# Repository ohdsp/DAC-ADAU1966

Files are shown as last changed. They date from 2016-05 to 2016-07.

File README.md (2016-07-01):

# [Open Hardware DSP Platform](http://www.ohdsp.org)
## ADAU1966 DAC with passive output filters
### Revision 2.0
###### DAC-ADAU1966 (KiCad 4.0.2-stable)
---
# README
### Disclaimer
Copyright Paul Janicki 2016

Licensed under the TAPR Open Hardware License (www.tapr.org/OHL)

This documentation is distributed WITHOUT ANY EXPRESS OR IMPLIED WARRANTY, INCLUDING OF MERCHANTABILITY, SATISFACTORY QUALITY AND FITNESS FOR A PARTICULAR PURPOSE.

### What is this repository? ###

**Quick summary**

This is a digital to analogue converter based on the ADAU1966 DAC chip from Analog Devices. This is designed as part the Open Hardware DSP Platform. This may or may not be suitable for use in other applications. 

This simple 16 channel DAC is designed to be used with 4xTDM4, 2xTDM8 or 1xTDM16 data inputs supported on devices such as the ADAU1452. This board can be used with the ADAU1966 in standalone mode (no host microcontroller needed) or with an external I2C interface to program/control the ADAU1966. The board uses only passive output filters on the ADAU1966 but can easily drive external PCBs through appropriate cabling.

This repository contains the KiCad design files, manufacturing Gerber/drill files, and PDF/drawing files for this board.

### What is the project folder structure?
Most folder names are self explanatory. Starting from the top level: \
*DAC-ADAU1966*
+ *Bill of Materials*  - This contains the bill of materials in CVS, LibreOffice Calc and XML formats
+ *Drawings*
    + *PCB* - This contains SVG and PDF outputs of PCB copper layers and assembly drawings
    + *Schematics* - This contains the PDF schematic drawing
+ *Gerbers* - This contains the PCB Gerbers and drill drawings for manufacture, there is also a zip file ready to send to most manufacturers
+ *KiCad* - This contains the original KiCad schematic and PCB design files

### How do I get set up? ###

**Summary of set up**

1. Set your self up a directory on a local disk, something simple will make life easier (eg C:\Electronics on Windows as used here), but anywhere will do just fine.
2. Download the Kicad-Libs from [https://github.com/ohdsp/KiCad-Libs](https://github.com/ohdsp/KiCad-Libs) and place in C:\Electronics\Kicad-Libs (or your chosen folder) 
3. Create a OHDSP subdirectory in C:\Electronics (so C:\Electronics\OHDSP)
3. Download this project to C:\Electronics\OHDSP\DAC-ADAU1966
4. Fire up Kicad
5. Open the main project file C:\Electronics\OHDSP\DAC-ADAU1966\Schematics\DAC-ADAU1966.pro
6. (Optional) Setup Pcbnew component library as below.
7. Do as you wish with the project, just keep it under the TAPR Open Hardware License.

Make sure your git setup doesn't exclude files used in the project (like .LIB files) or things may go wrong down the line.

**KiCad Library Configuration**

Note that you need to setup a Pcbnew library, but the eeschema libraries should work without any changes if you followed the instructions above.

To setup Pcbnew libraries:

In Pcbnew go to Preferences -> Footprint Libraries Manager. Under Global Libraries tab in the top list check if there is a nickname "MyKiCadLibs-Footprints" (usually at the end of the list). If there is but it points to the wrong place then change the Library Path to point to MyKiCadLibs-Footprints (eg C:\Electronics\KiCad-Libs\MyKiCadLibs-Footprints.pretty) folder for your setup. If this is missing you can use "Append with Wizard", choose "Files on my computer", click next, browse to library location (eg C:\Electronics\KiCad-Libs\MyKiCadLibs-Footprints.pretty) and select the folder MyKiCadLibs-Footprints.pretty, click next, check the Status column states OK and the Format is KiCad (if not re-download the library) and click next, then select "To global library configuration..." and click Finish.

To setup eeschema component libraries:
Either from KiCad project window go to Tools -> Run Library Editor OR under eeschema, go to Tools -> Library Editor. Then Preferences -> Component Libraries.

The top section "Component Library Files" should ideally contain only two libraries, the "power" library that ships with KiCad and "MyKiCadLibs-Lib" available from above. To setup MyKiCadLibs-Lib as a relative path under the "User defined search path" click add. Browse to the location of KiCad-Libs you download above (eg C:\Electronics\KiCad-Libs) and click "Select Folder". Say yes to add a relative path. Under component library files click add, browse to the KiCad-libs again (eg C:\Electronics\KiCad-Libs), select file "MyKiCadLibs-Lib.lib" and click open. MyKiCadLibs-lib should appear in the component library list with no path as it will be using the user defined search path set in the box below.

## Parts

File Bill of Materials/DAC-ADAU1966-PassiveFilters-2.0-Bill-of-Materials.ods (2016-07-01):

DAC-ADAU1966 Bill of Materials – Revision 2.0
25 May 2016
Reference | Quantity | Footprint | Value | Description | Power | Size | Tolerance | Voltage | Type | Current
C301 C306 C312 | 3 | CAP-TH-D8mmP3.5mm | 220u | 'Aluminium electrolytic low impedance capacitor - eg Panasonic FC or FR parts | ' | '3.5mm Pitch, 8mm Diameter | ' | '25V | ' | '
C302 C307 C308 C315 | 4 | SMD-0805 | 22u | 'Ceramic capacitor | ' | '0805 | '20% | '25V | 'X5R | '
C303 C310 C311 C316 C321 C324 C328 C404 C422 C426 C428 C430 C434 C436 C439 C441 C446 C450 C460 | 19 | SMD-0805 | 100n | 'Ceramic capacitor | ' | '0805 | '10% | '50V | 'X7R | '
C305 C313 C314 C318 C322 C326 C329 C447 C451 | 9 | SMD-0805 | 10n | 'Ceramic capacitor | ' | '0805 | '10% | '50V | 'X7R | '
C304 C309 C401 C419 C437 | 5 | SMD-0805 | 100p | 'Ceramic capacitor | ' | '0805 | '5% | '50V | 'C0G | '
C325 C402 C418 C421 C424 C438 | 6 | CAP-TH-D6.3mmP2.5mm | 220u | 'Aluminium electrolytic low impedance capacitor - eg Panasonic FC or FR parts | ' | '2.5mm Pitch, 6.3mm Diameter | ' | '10V | ' | '
C317 C320 C323 C327 C403 C416 C420 C423 C427 C440 | 10 | SMD-0805 | 22u | 'Ceramic capacitor | ' | '0805 | '20% | '10V | 'X5R | '
C405 C408 C412 C429 C432 C452 C454 C456 C458 | 9 | SMD-0603 | 1u | 'Ceramic capacitor | ' | '0603 | '10% | '10V | 'X7R | '
C406 C409 C414 C417 C431 C433 C453 C455 C457 C459 | 10 | SMD-0603 | 100n | 'Ceramic capacitor | ' | '0603 | '10% | '50V | 'X7R | '
C407 C410 C415 | 3 | SMD-0603 | 10n | 'Ceramic capacitor | ' | '0603 | '10% | '50V | 'X7R | '
C411 | 1 | SMD-0603 | 5n6 | 'Ceramic capacitor | ' | '0603 | '10% | '50V | 'X7R | '
C413 | 1 | SMD-0603 | 390p | 'Ceramic capacitor | ' | '0603 | '5% | '50V | 'C0G | '
C425 C461 | 2 | SMD-0805 | 10u | 'Ceramic capacitor | ' | '0805 | '20% | '10V | 'X5R | '
C435 | 1 | SMD-0805 | N/F | 'Ceramic capacitor | ' | '0805 | '10% | '50V | 'X7R | '
C442 C444 C445 C448 | 4 | SMD-0603 | 470n | 'Ceramic capacitor | ' | '0603 | '10% | '10V | 'X7R | '
C443 C449 | 2 | CAP-TH-D6.3mmP2.5mm | 47u | 'Aluminium electrolytic low impedance capacitor - eg Panasonic FC or FR parts | ' | '2.5mm Pitch, 6.3mm Diameter | ' | '10V | ' | '
C501 C502 C503 C504 C505 C506 C507 C508 C509 C510 C511 C512 C513 C514 C515 C516 | 16 | SMD-0805 | 2n7 | 'Ceramic capacitor | ' | '0805 | '5% | '50V | 'C0G | '
D301 D302 D303 D304 D306 D307 D308 D310 | 8 | DIODE-SOD-123 | SS14L | 'SS14L 1A 40V Schottky rectifier - Sub-SMA (SOD-123) | ' | ' | ' | ' | ' | '
D305 | 1 | DIODE-SOD-123 | B130LAW-7-F | '1A 30V Schottky Rectifier - SOD-123 - Low Vf (<0.3V@100mA) | ' | ' | ' | ' | ' | '
D309 | 1 | SMD-1206 | Green LED 1206 | 'Green LED - SMD - Vf 1.8V to 2.2V | ' | '1206 | ' | ' | ' | '
FID1 FID2 FID3 FID4 | 4 | FID-1MM-3MM | MNT_HOLE | 'Fiducial | ' | ' | ' | ' | ' | '
JP401 JP402 JP403 JP404 JP405 JP406 JP407 P410 | 8 | CONN_SIL_2_1MM | CONN_2x1 | '1x2 2.54mm pitch pin header | ' | ' | ' | ' | ' | '
L301 L302 L401 L402 L403 | 5 | SMD-0805 | 600R@100MHz | 'Ferrite bead, current rating 0.3A or higher, 600R@100MHz | ' | '0805 | ' | ' | ' | '=>0.3A
MNT301 MNT302 MNT303 MNT304 | 4 | MNT_HOLE_3.2mm | MNT_HOLE
P201 P202 P203 P204 | 4 | CONN_DIL_2X5_BOX_1MM | CONN_02X05 | '2x5 2.54mm pitch box header | ' | ' | ' | ' | ' | '
P205 | 1 | CONN_SIL_3_1MM | CONN_3x1 | '1x3 2.54mm pitch pin header | ' | ' | ' | ' | ' | '
P206 | 1 | CONN_DIL_2X6_BOX_1MM | CONN_02X06 | '2x6 2.54mm pitch box header | ' | ' | ' | ' | ' | '
P303 P304 | 2 | CONN-2WAY-2.54mm-3.81mm-SPACING | CONN_2x1 | '2 way screw terminal, 2.54mm to 3.81mm pitch | ' | ' | ' | ' | ' | '
P501 P502 P503 P504 | 4 | CONN_DIL_2X10_BOX_1MM | CONN_02X10 | '2x10 2.54mm pitch box header | ' | ' | ' | ' | ' | '
R101 R102 R419 | 3 | SMD-0805 | 1k | 'Thick or thin film resistor | '100mW | '0805 | '1% | ' | ' | '
R201 R202 R203 R204 R205 R206 R207 R214 R215 | 9 | SMD-0805 | N/F | 'Thick or thin film resistor | '100mW | '0805 | '1% | ' | ' | '
R208 R209 R210 R211 R212 R213 R216 R217 R218 R401 R405 R407 R409 R412 R414 R416 | 16 | SMD-0805 | 10k | 'Thick or thin film resistor | '100mW | '0805 | '1% | ' | ' | '
R219 R220 R221 R222 R223 R224 R225 R227 R228 R229 R230 R231 R310 | 13 | SMD-0805 | 0 | 'Thick or thin film resistor | '100mW | '0805 | '1% | ' | ' | '
R226 | 1 | SMD-0805 | 75 | 'Thick or thin film resistor | '100mW | '0805 | '1% | ' | ' | '
R301 R302 R402 R418 R422 | 5 | SMD-0805 | 47 | 'Thick or thin film resistor | '100mW | '0805 | '1% | ' | ' | '
R303 | 1 | SMD-0805 | 47k | 'Thick or thin film resistor | '100mW | '0805 | '1% | ' | ' | '
R309 | 1 | SMD-0805 | 2k2 | 'Thick or thin film resistor | '100mW | '0805 | '1% | ' | ' | '
R311 | 1 | SMD-0805 | 6k8 | 'Thick or thin film resistor | '100mW | '0805 | '1% | ' | ' | '
R312 | 1 | SMD-0805 | 470 | 'Thick or thin film resistor | '100mW | '0805 | '1% | ' | ' | '
R411 | 1 | SMD-0603 | 562 | 'Thick or thin film resistor | '100mW | '0805 | '1% | ' | ' | '
R420 | 1 | SMD-0805 | 100k | 'Thick or thin film resistor | '100mW | '0805 | '1% | ' | ' | '
R421 | 1 | SMD-0805 | 100 | 'Thick or thin film resistor | '100mW | '0805 | '1% | ' | ' | '
R501 R502 R503 R504 R505 R506 R507 R508 R509 R510 R511 R512 R513 R514 R515 R516 R549 R550 R551 R552 R553 R554 R555 R556 R557 R558 R559 R560 R561 R562 R563 R564 | 32 | SMD-1206 | 240 | 'MELF0204 1% =>250mW or 1206 1% =>250mW | '250mW | '1206 | '1% | ' | ' | '
R517 R518 R519 R520 R521 R522 R523 R524 R525 R526 R527 R528 R529 R530 R531 R532 R565 R566 R567 R568 R569 R570 R571 R572 R573 R574 R575 R576 R577 R578 R579 R580 | 32 | SMD-1206 | 100 | 'MELF0204 1% =>250mW or 1206 1% =>250mW | '250mW | '1206 | '1% | ' | ' | '
R533 R534 R535 R536 R537 R538 R539 R540 R541 R542 R543 R544 R545 R546 R547 R548 R581 R582 R583 R584 R585 R586 R587 R588 R589 R590 R591 R592 R593 R594 R595 R596 | 32 | SMD-1206 | 100k | 'MELF0204 1% =>250mW or 1206 1% =>250mW | '250mW | '1206 | '1% | ' | ' | '
TP101 | 1 | TP-1mm | Test point | '1mm test point | ' | ' | ' | ' | ' | '
TP401 TP402 | 2 | TP-2mm | Test point | 'Test point | ' | ' | ' | ' | ' | '
U301 | 1 | IC-SOT-223 | TLV1117LV33DCY | 'TLV1117LV 1-A, Positive Fixed-Voltage, Low-Dropout Regulator - Fixed 3V3 | ' | ' | ' | ' | ' | '
U302 | 1 | IC-SOT23-5 | TLV70025DDC | 'TLV700 200-mA, Low-IQ, Low-Dropout Regulator for Portable Devices - Fixed 2V5 | ' | ' | ' | ' | ' | '
U303 | 1 | IC-SOT223-6 | TPS7A4501 | 'TPS7A45xx Low-Noise Fast-Transient-Response 1.5-A Low-Dropout Voltage Regulators - Adjustable | ' | ' | ' | ' | ' | '
U401 | 1 | IC-SOT143 | ADM811ZART | 'Microprocessor Supervisory - 2V32 Typical Threshold | ' | ' | ' | ' | ' | '
U402 | 1 | IC-LQFP80-P065 | IC-DAC-ADAU1966 | '16-Channel High Performance Differential Output, 192 kHz, 24-Bit DAC | ' | ' | ' | ' | ' | '

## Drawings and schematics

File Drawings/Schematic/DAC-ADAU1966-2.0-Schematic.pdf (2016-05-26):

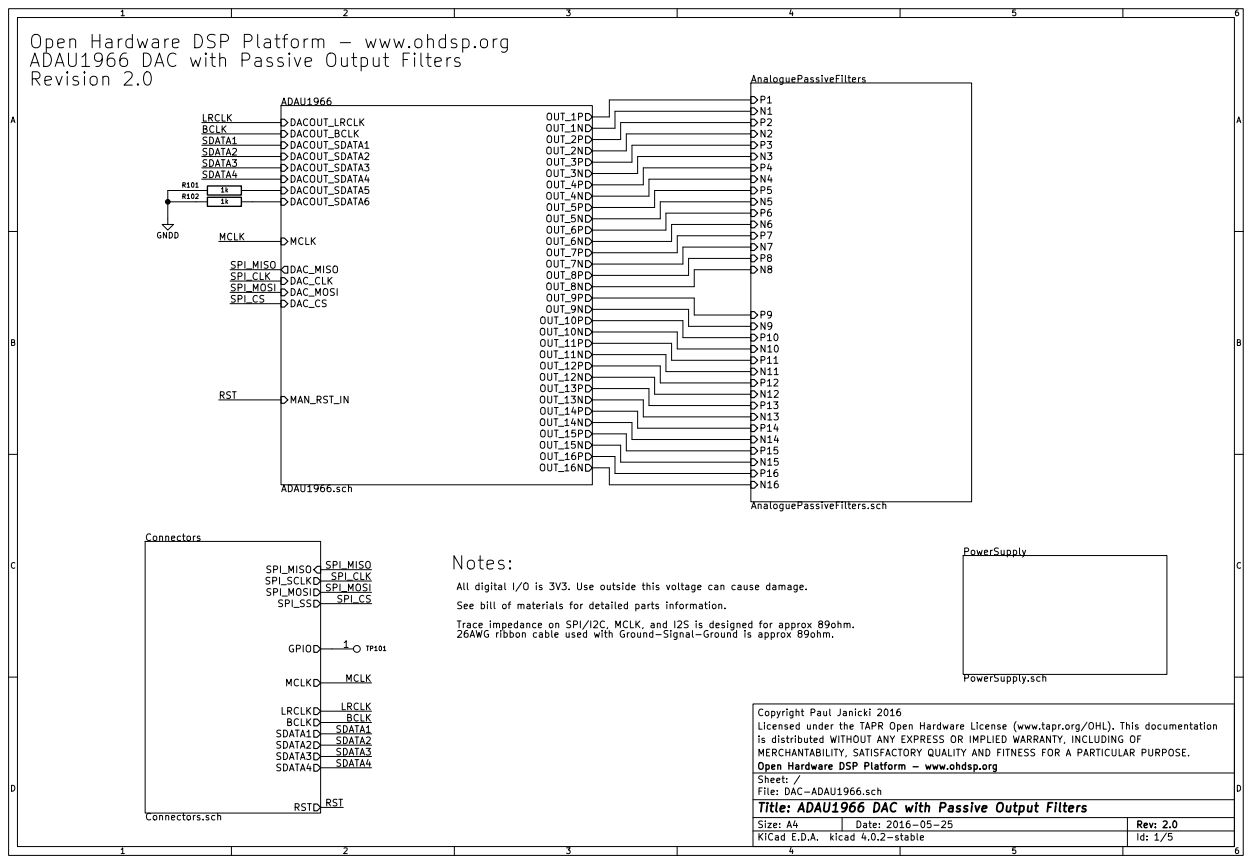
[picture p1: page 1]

AnaloguePassiveFilters.sch P1N1P2N2P3N3P4N4P5N5P6N6P7N7P8N8P9N9P10 N10 P11 N11 P12 N12 P13 N13 P14 N14 P15 N15 P16 N16 Open Hardware DSP Platform - www.ohdsp.org
ADAU1966 DAC with Passive Output Filters
Revision 2.0

SPI_CLK
SPI_MOSI

All digital I/O is 3V3. Use outside this voltage can cause damage.
See bill of materials for detailed parts information.
Trace impedance on SPI/I2C, MCLK, and I2S is designed for approx 89ohm.
26AWG ribbon cable used with Ground-Signal-Ground is approx 89ohm.

Copyright Paul Janicki 2016
Licensed under the TAPR Open Hardware License (www.tapr.org/OHL). This documentation
is distributed WITHOUT ANY EXPRESS OR IMPLIED WARRANTY, INCLUDING OF
MERCHANTABILITY, SATISFACTORY QUALITY AND FITNESS FOR A PARTICULAR PURPOSE.
File: DAC-ADAU1966.sch Sheet: / Open Hardware DSP Platform - www.ohdsp.org

Id: 1/5 Title: ADAU1966 DAC with Passive Output Filters

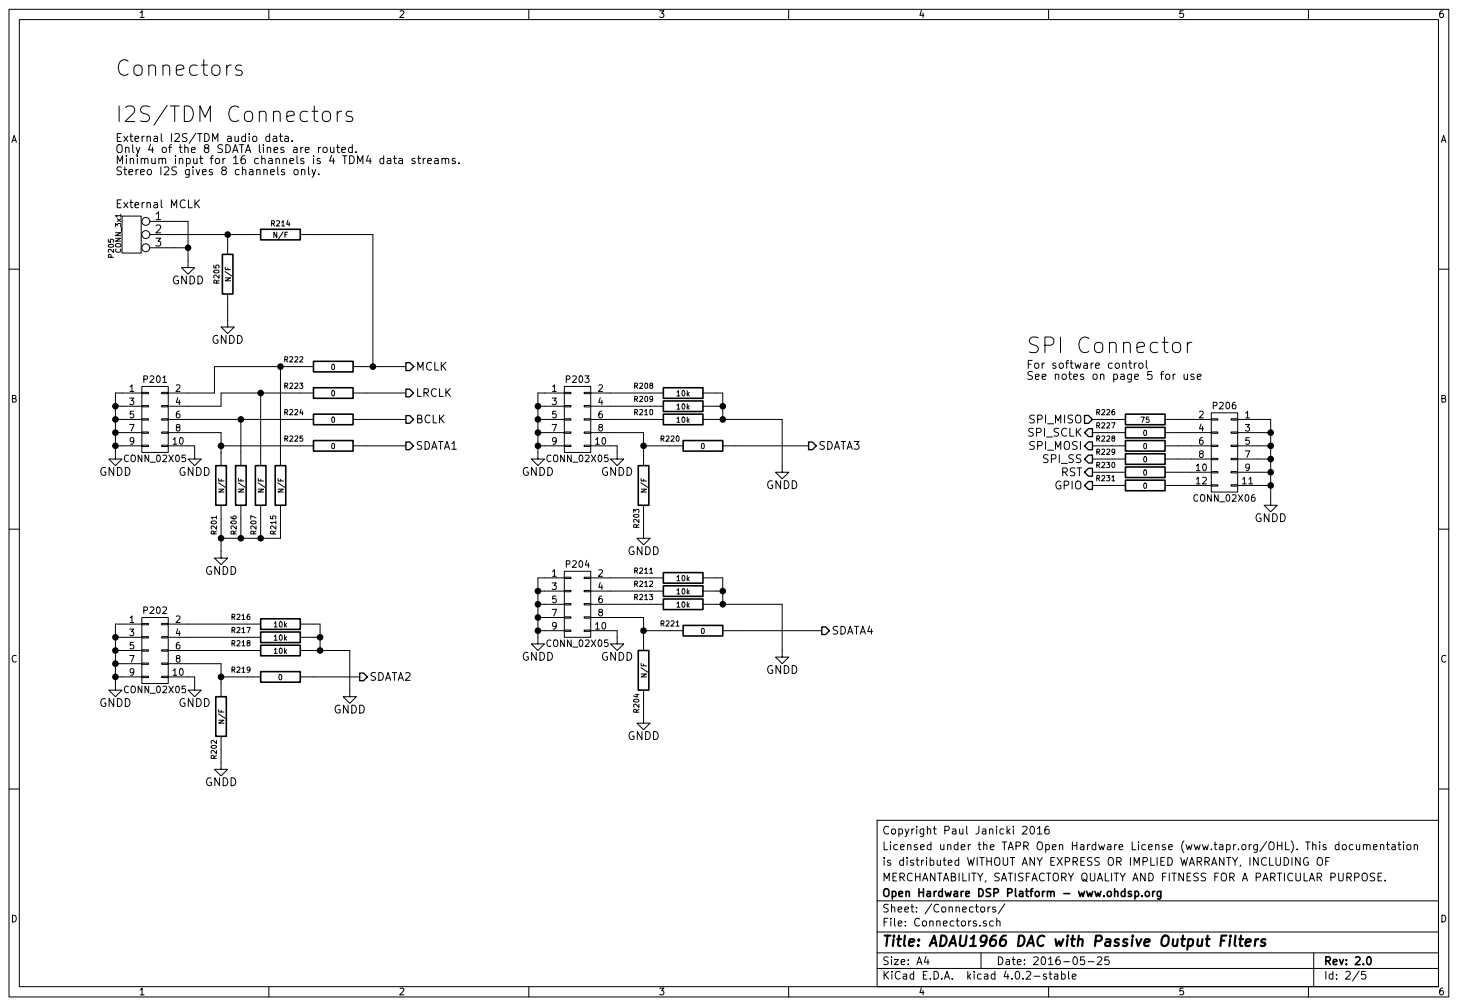
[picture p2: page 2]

External I2S/TDM audio data.
Only 4 of the 8 SDATA lines are routed.
Minimum input for 16 channels is 4 TDM4 data streams.
Stereo I2S gives 8 channels only.

0 For software control See notes on page 5 for use

10 | 9

Copyright Paul Janicki 2016
Licensed under the TAPR Open Hardware License (www.tapr.org/OHL). This documentation
is distributed WITHOUT ANY EXPRESS OR IMPLIED WARRANTY, INCLUDING OF
MERCHANTABILITY, SATISFACTORY QUALITY AND FITNESS FOR A PARTICULAR PURPOSE.
File: Connectors.sch Sheet: /Connectors/ Open Hardware DSP Platform - www.ohdsp.org

Id: 2/5 Title: ADAU1966 DAC with Passive Output Filters

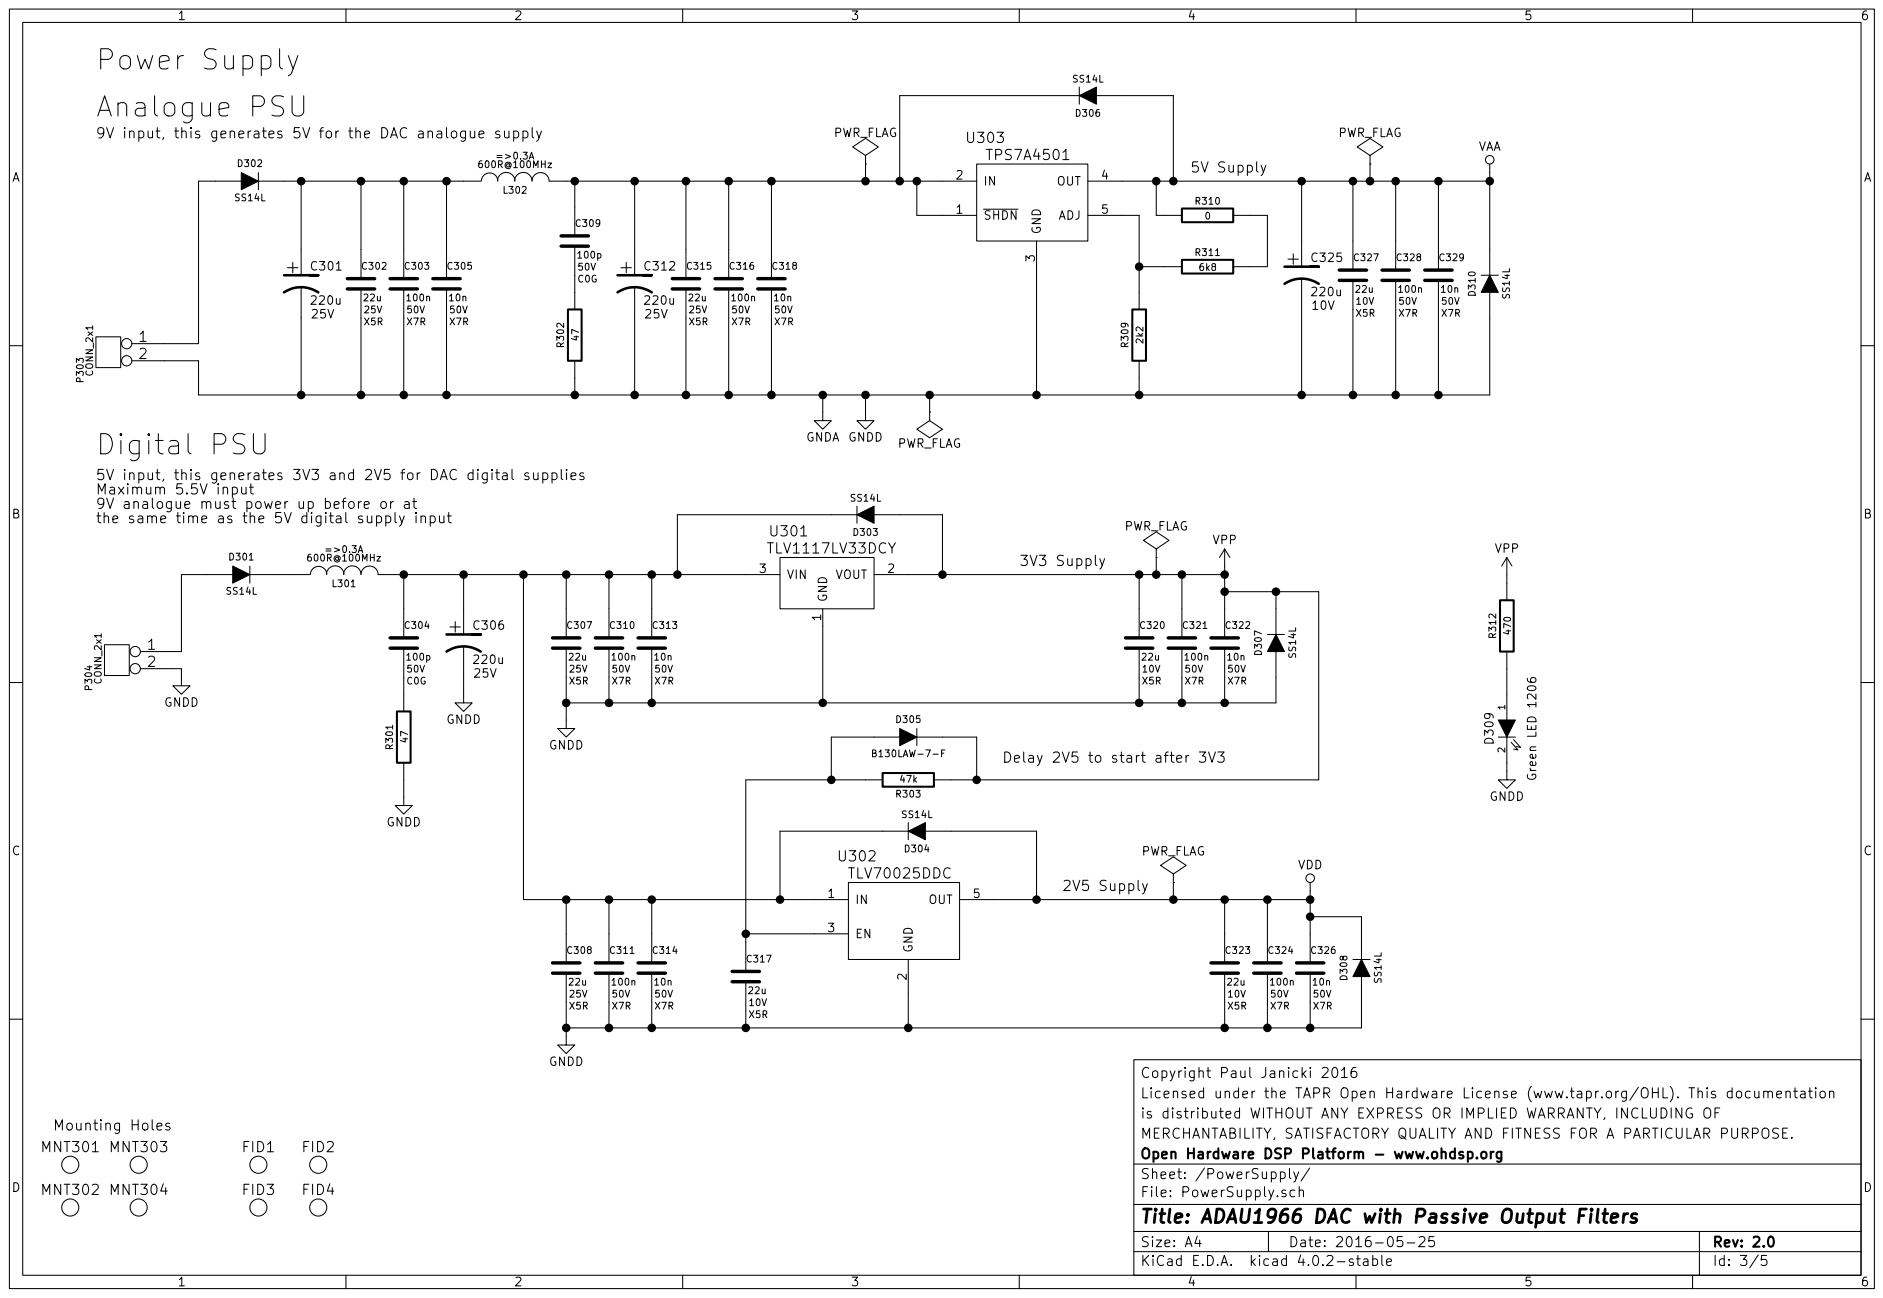
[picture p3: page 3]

9V input, this generates 5V for the DAC analogue supply

Copyright Paul Janicki 2016 GNDA GNDD

5V input, this generates 3V3 and 2V5 for DAC digital supplies
Maximum 5.5V input
9V analogue must power up before or at
the same time as the 5V digital supply input

Licensed under the TAPR Open Hardware License (www.tapr.org/OHL). This documentation
is distributed WITHOUT ANY EXPRESS OR IMPLIED WARRANTY, INCLUDING OF
MERCHANTABILITY, SATISFACTORY QUALITY AND FITNESS FOR A PARTICULAR PURPOSE.
Open Hardware DSP Platform - www.ohdsp.org
Sheet: /PowerSupply/
File: PowerSupply.sch
Id: 3/5 Title: ADAU1966 DAC with Passive Output Filters

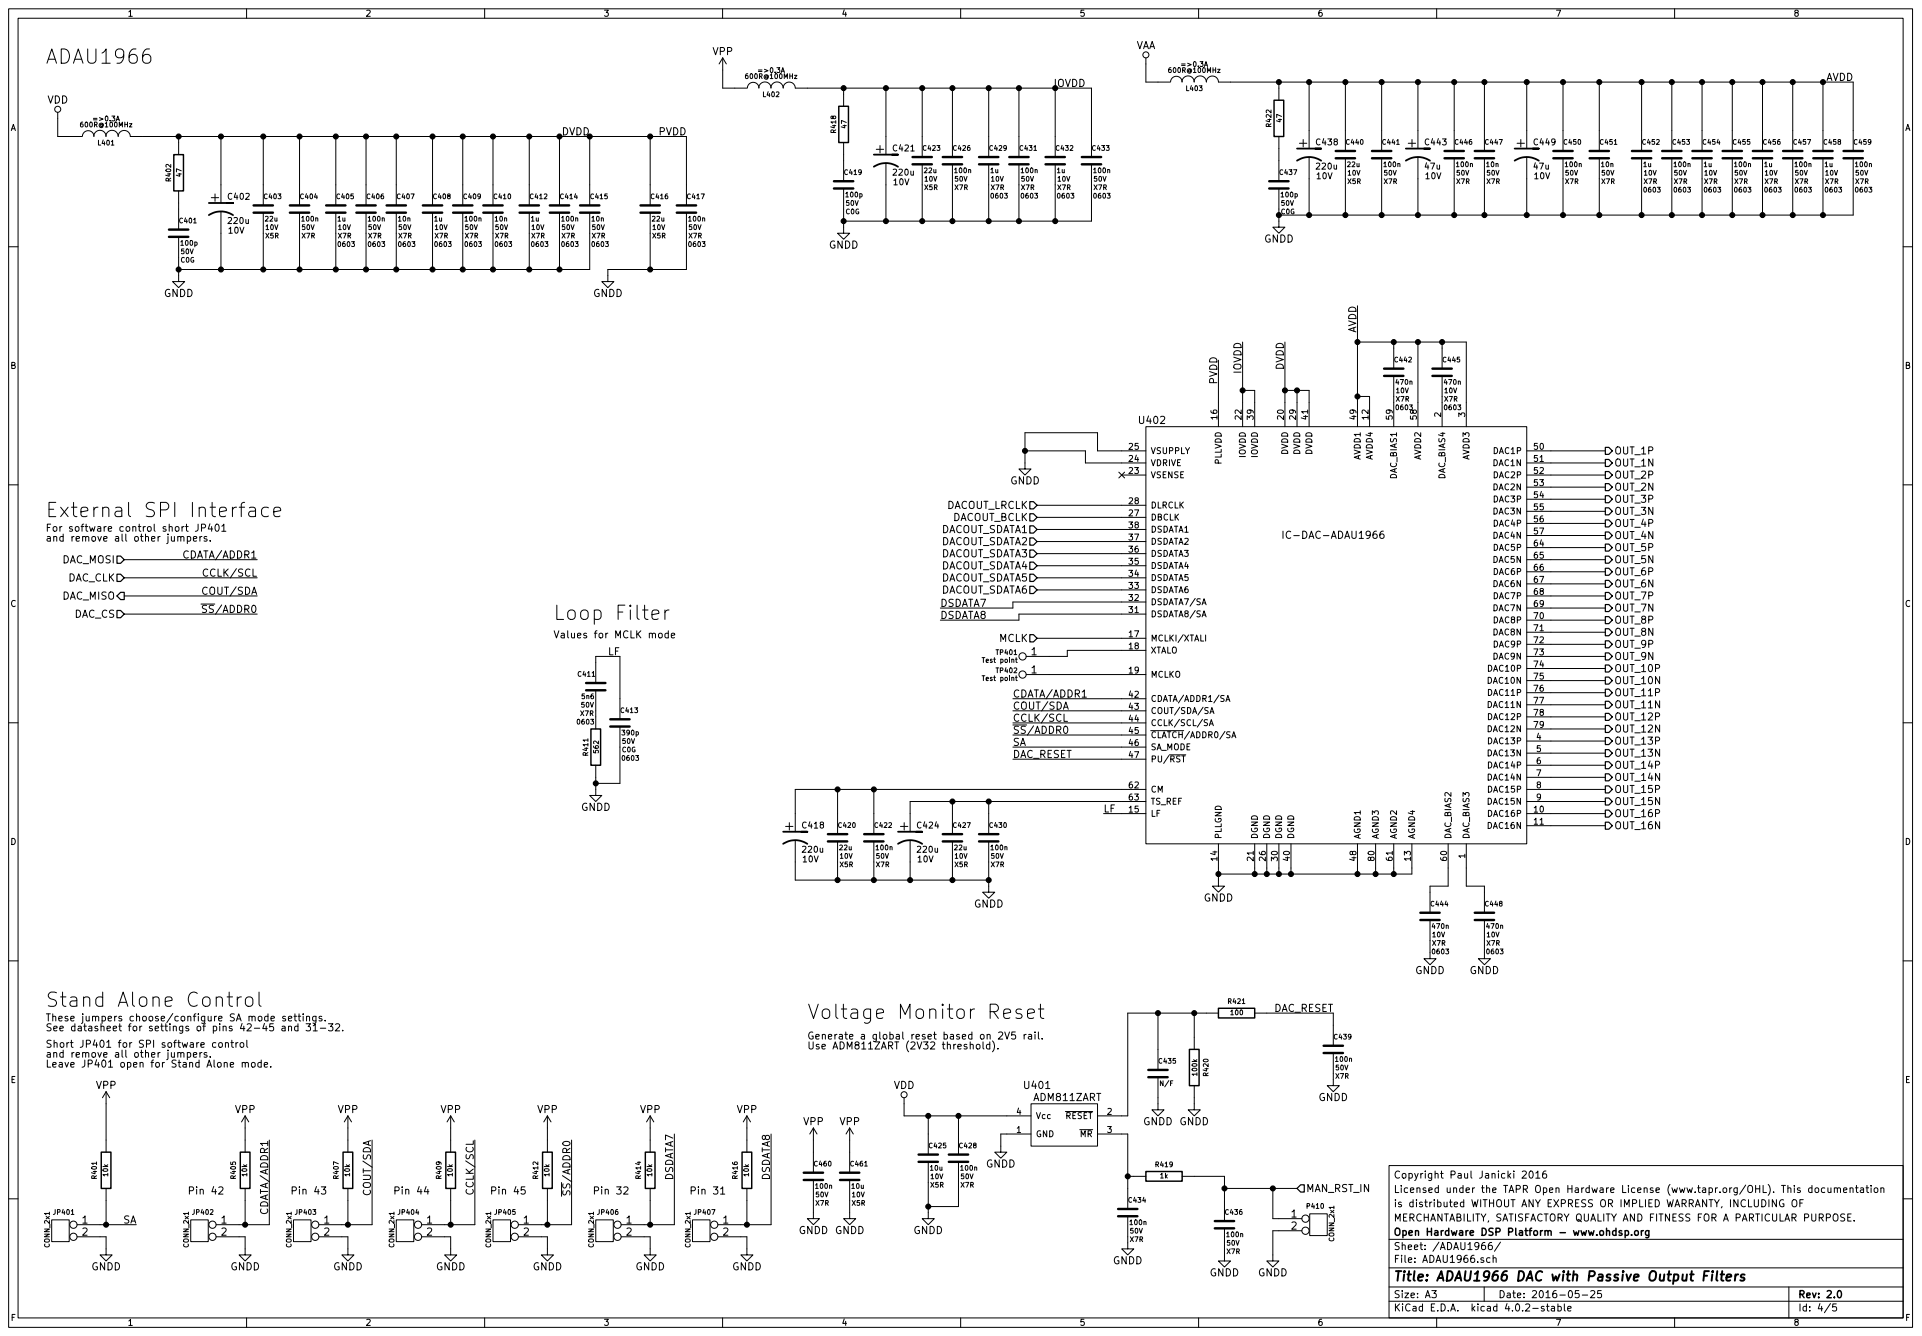
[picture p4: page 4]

3 DAC13P 4 DAC13N 5 DAC14P 6 DAC14N 7 DAC15P 8 DAC15N 9 DAC16P 10 DVDD 20 DGND 30 DGND 40 DAC1P 50 DAC_BIAS2 60 DAC8P 70 AGND3 80 DAC16N 11 DGND 21 DSDATA8/SA 31 DVDD 41 DAC1N 51 AGND2 61 DAC8N 71 AVDD4 12 IOVDD 22 DSDATA7/SA 32 CDATA/ADDR1/SA 42 DAC2P 52 CM 62 DAC9P 72 AGND4 13 VSENSE 23 DSDATA6 33 COUT/SDA/SA 43 DAC2N 53 TS_REF 63 DAC9N 73 PLLGND 14 VDRIVE 24 DSDATA5 34 CCLK/SCL/SA 44 DAC3P 54 DAC5P 64 DAC10P 74

These jumpers choose/configure SA mode settings.
See datasheet for settings of pins 42-45 and 31-32.
Short JP401 for SPI software control and remove all other jumpers.
Leave JP401 open for Stand Alone mode.

Generate a global reset based on 2V5 rail.
Use ADM811ZART (2V32 threshold).

Copyright Paul Janicki 2016
Licensed under the TAPR Open Hardware License (www.tapr.org/OHL). This documentation
is distributed WITHOUT ANY EXPRESS OR IMPLIED WARRANTY, INCLUDING OF
MERCHANTABILITY, SATISFACTORY QUALITY AND FITNESS FOR A PARTICULAR PURPOSE.
File: ADAU1966.sch Sheet: /ADAU1966/ Open Hardware DSP Platform - www.ohdsp.org

Id: 4/5 Title: ADAU1966 DAC with Passive Output Filters

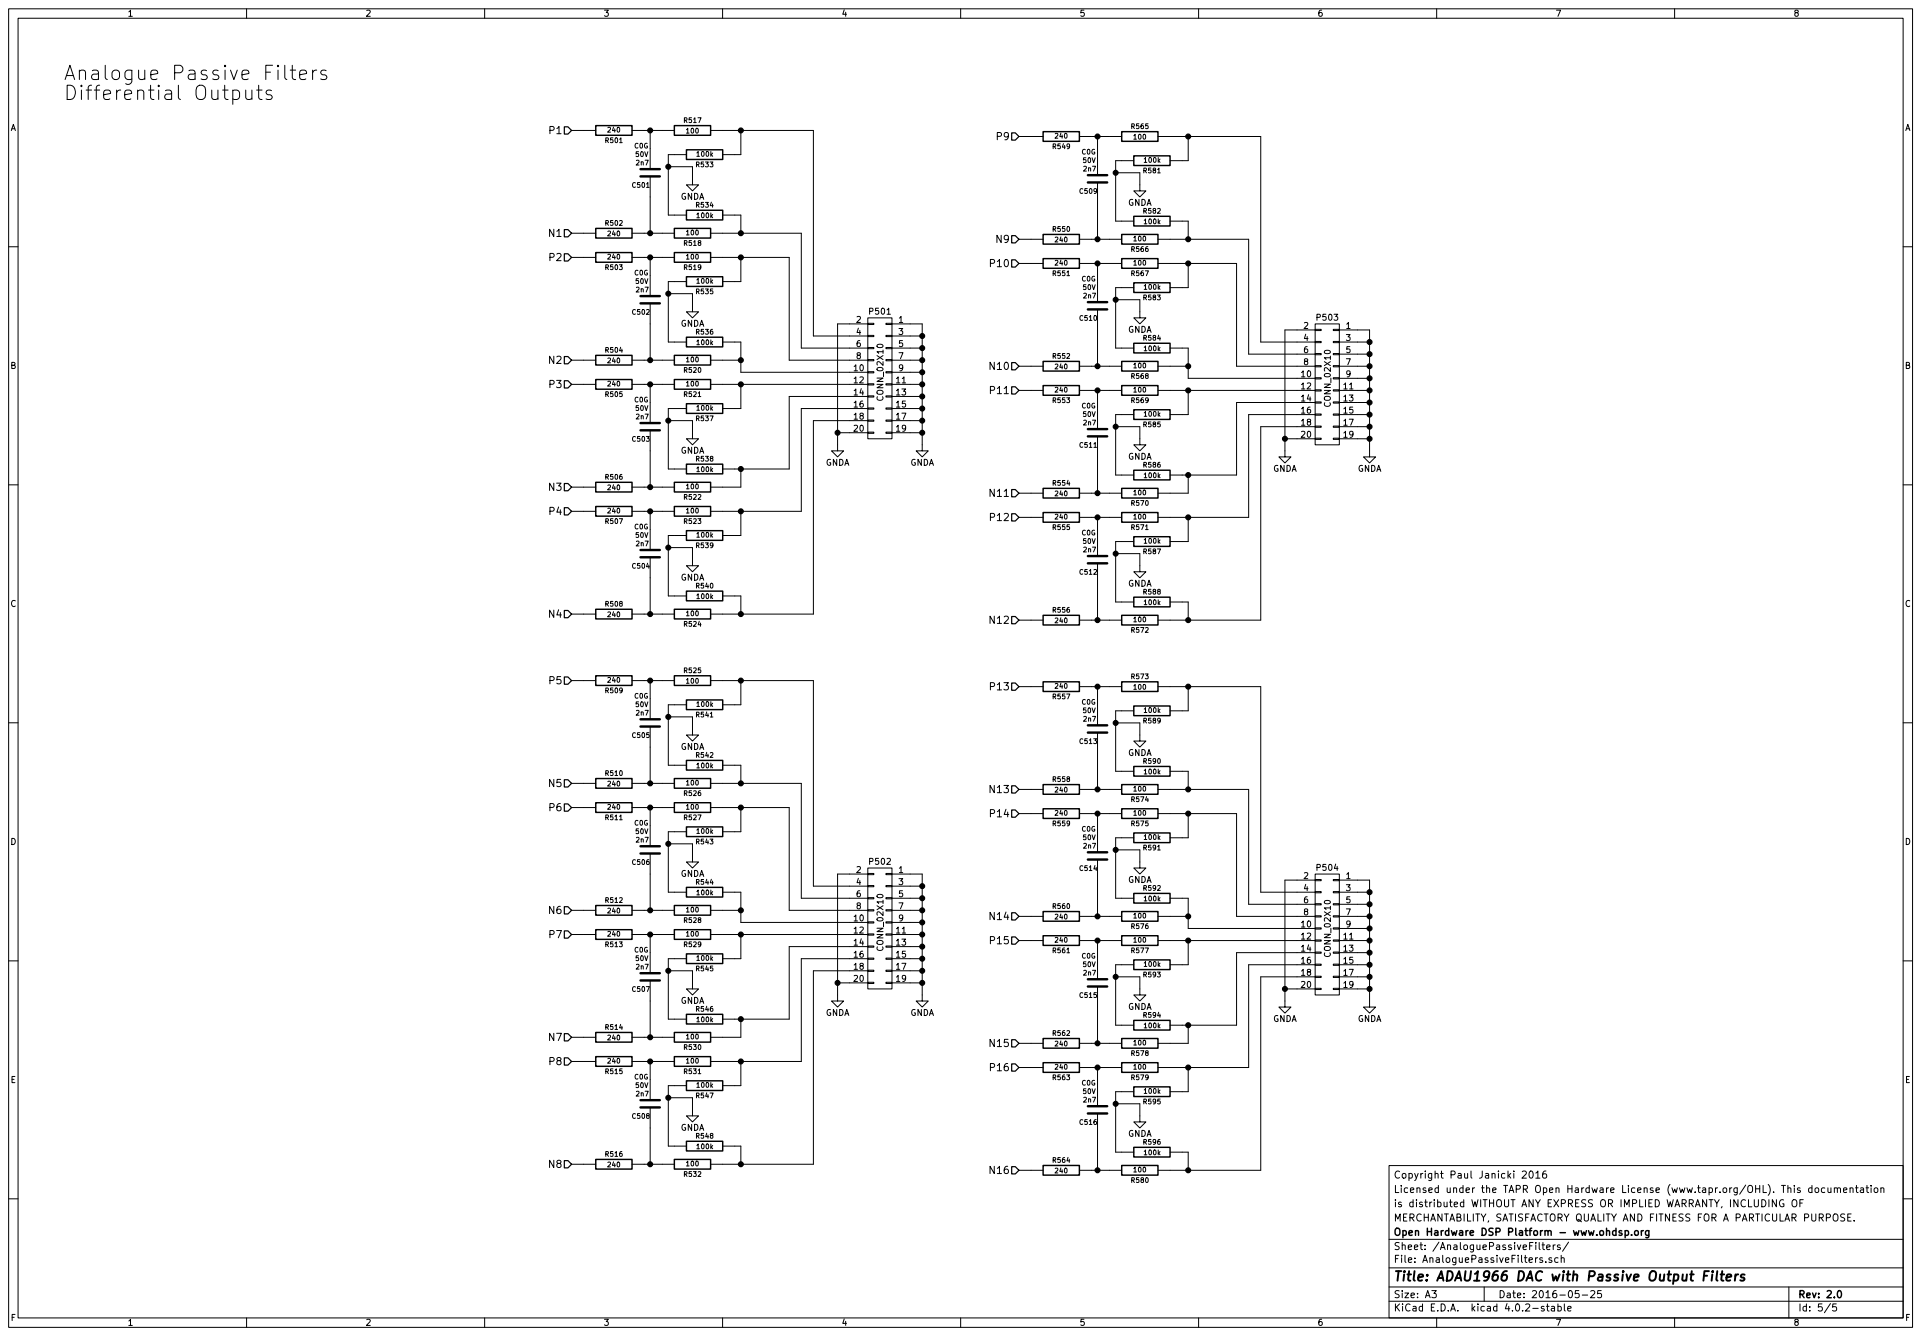
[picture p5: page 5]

10 | | 9
12 | | 11
14 | | 13
16 | | 15

18 | | 17

Copyright Paul Janicki 2016
Licensed under the TAPR Open Hardware License (www.tapr.org/OHL). This documentation
is distributed WITHOUT ANY EXPRESS OR IMPLIED WARRANTY, INCLUDING OF
MERCHANTABILITY, SATISFACTORY QUALITY AND FITNESS FOR A PARTICULAR PURPOSE.
Open Hardware DSP Platform - www.ohdsp.org
Sheet: /AnaloguePassiveFilters/
File: AnaloguePassiveFilters.sch
Id: 5/5 Title: ADAU1966 DAC with Passive Output Filters

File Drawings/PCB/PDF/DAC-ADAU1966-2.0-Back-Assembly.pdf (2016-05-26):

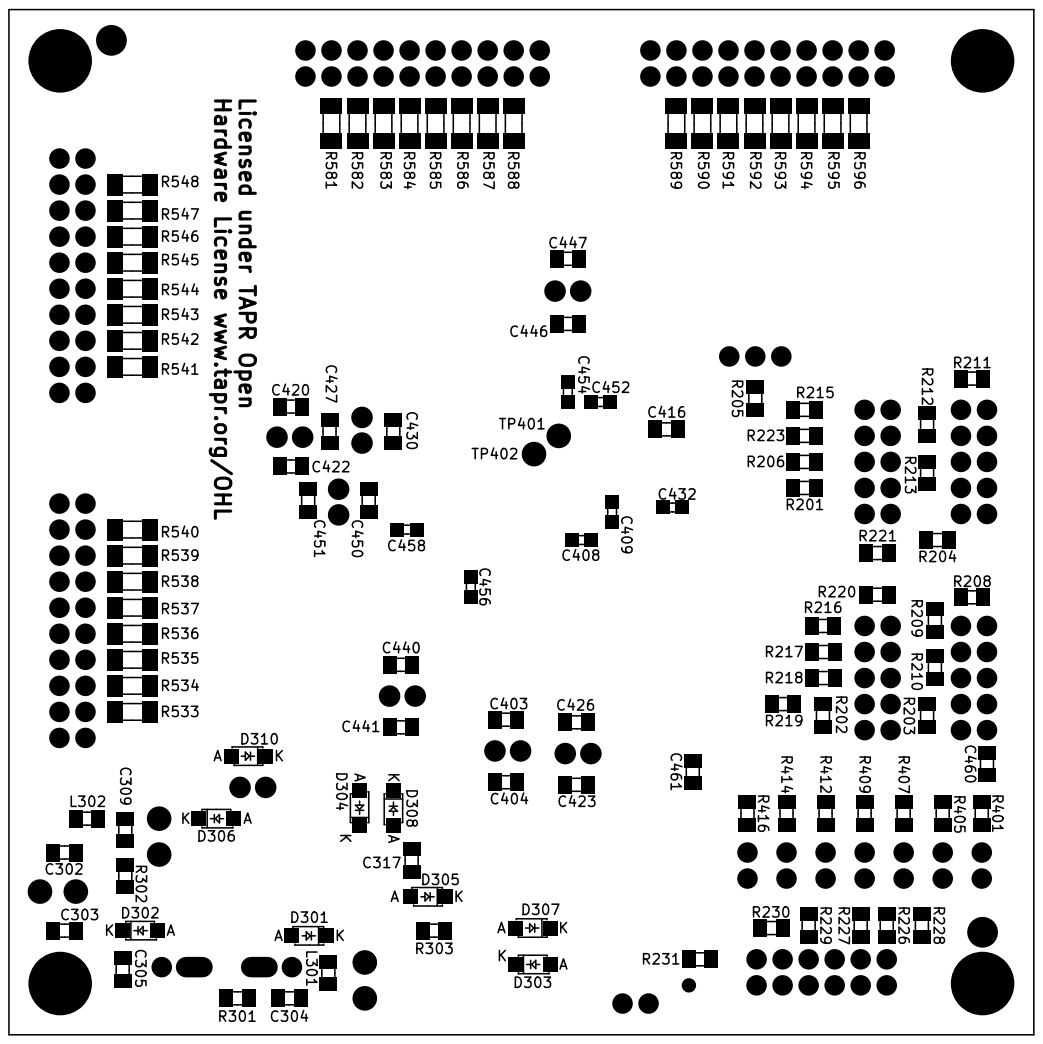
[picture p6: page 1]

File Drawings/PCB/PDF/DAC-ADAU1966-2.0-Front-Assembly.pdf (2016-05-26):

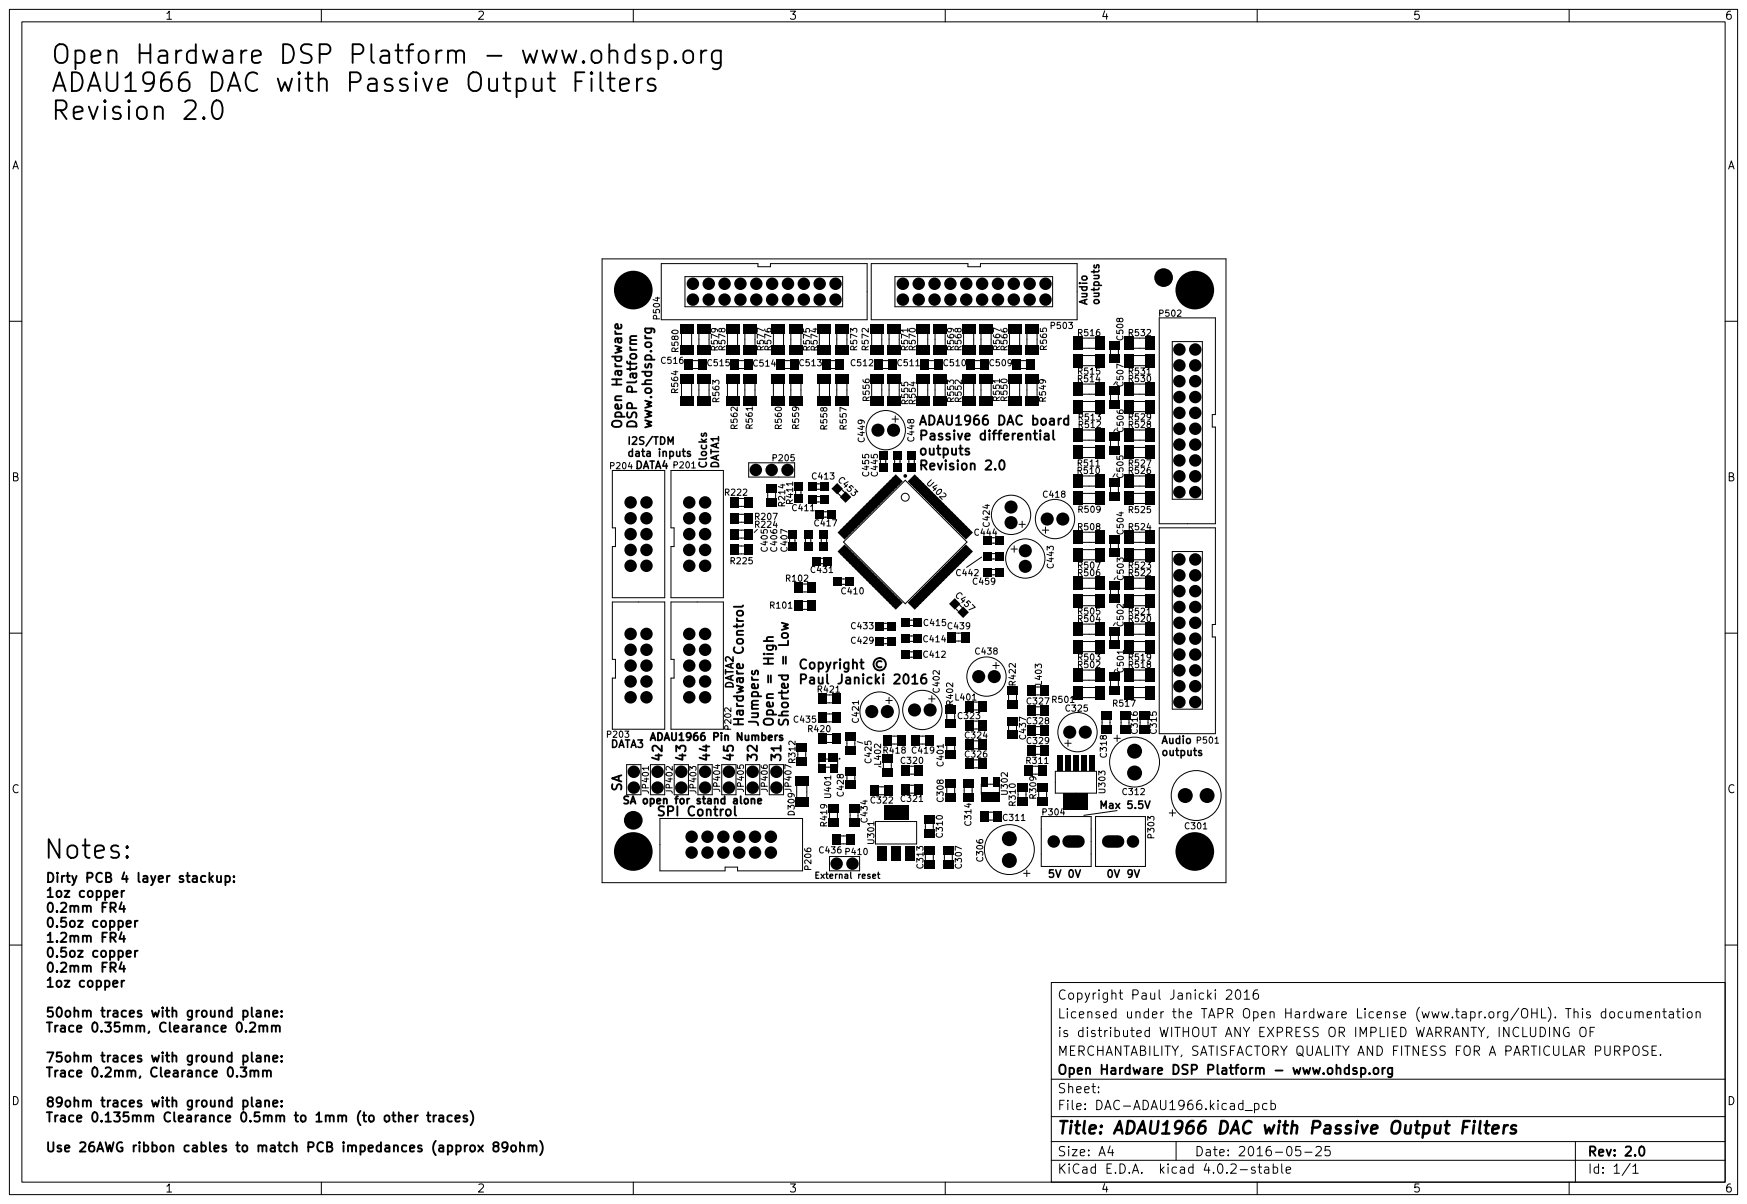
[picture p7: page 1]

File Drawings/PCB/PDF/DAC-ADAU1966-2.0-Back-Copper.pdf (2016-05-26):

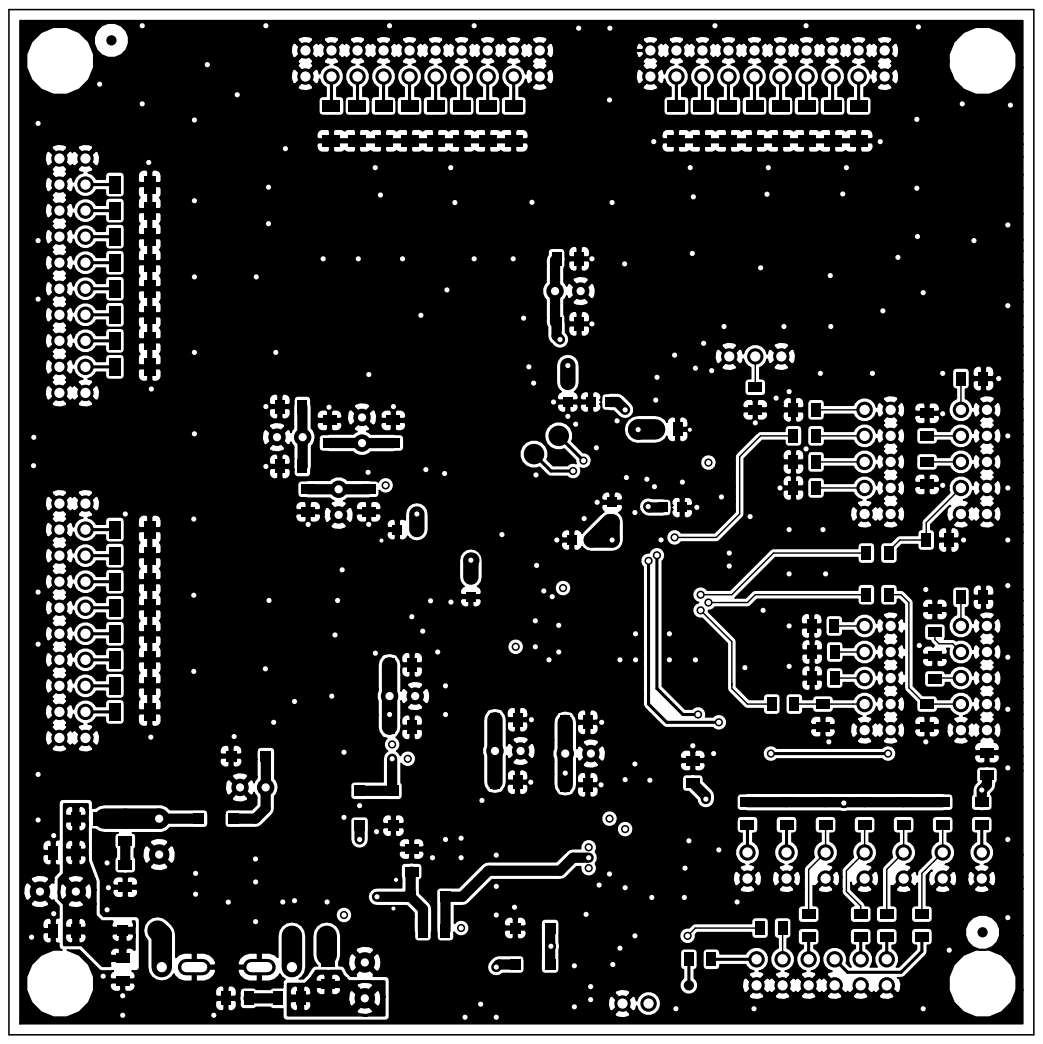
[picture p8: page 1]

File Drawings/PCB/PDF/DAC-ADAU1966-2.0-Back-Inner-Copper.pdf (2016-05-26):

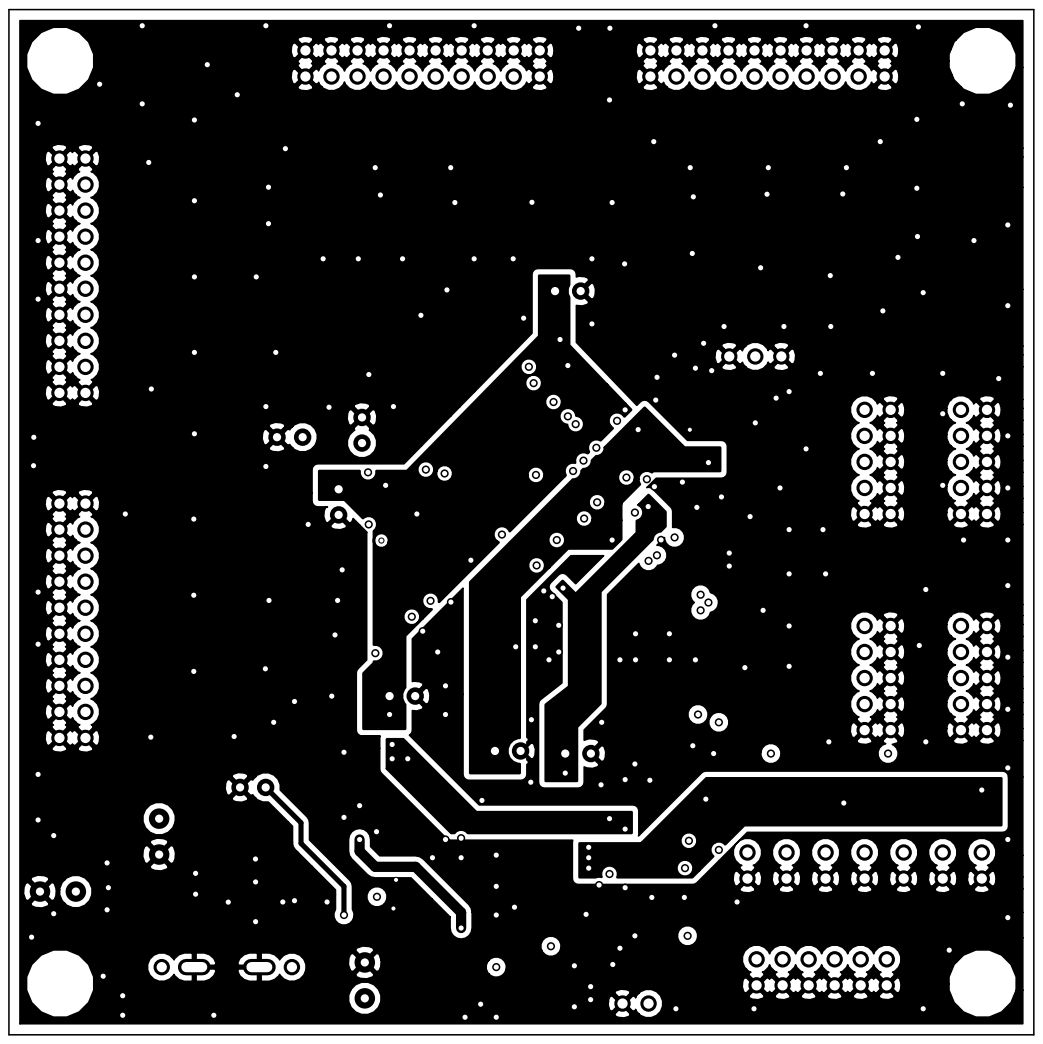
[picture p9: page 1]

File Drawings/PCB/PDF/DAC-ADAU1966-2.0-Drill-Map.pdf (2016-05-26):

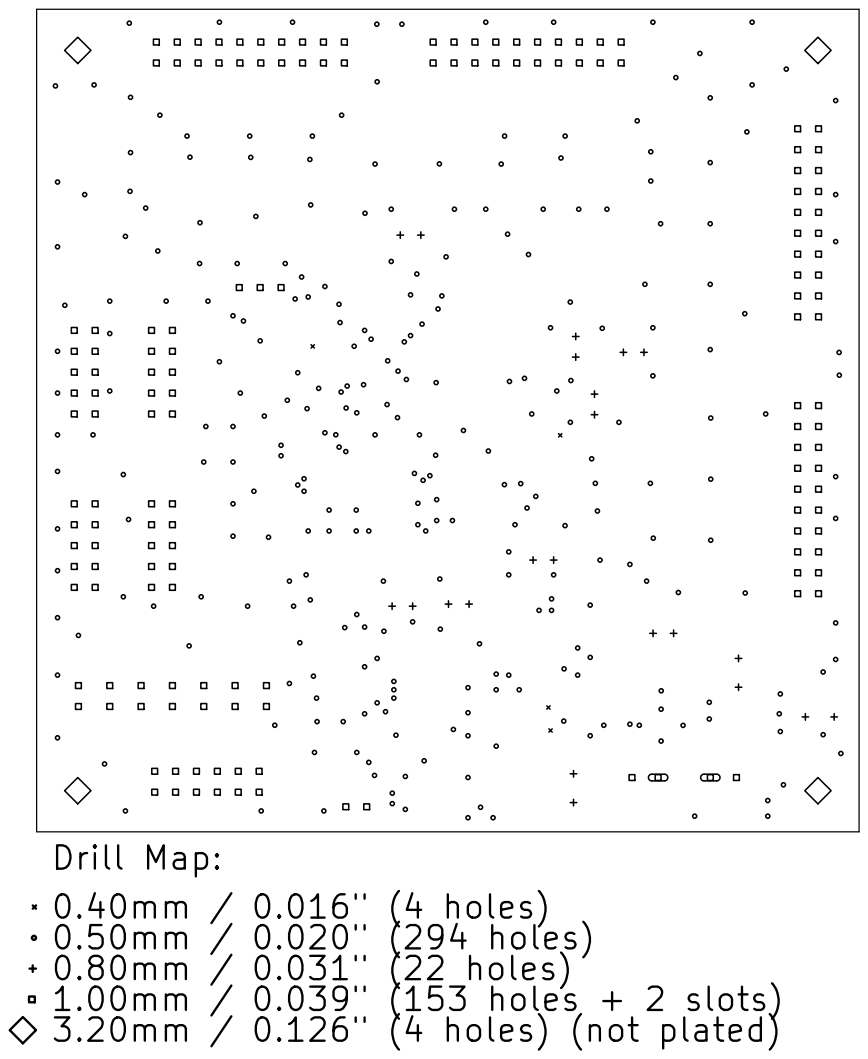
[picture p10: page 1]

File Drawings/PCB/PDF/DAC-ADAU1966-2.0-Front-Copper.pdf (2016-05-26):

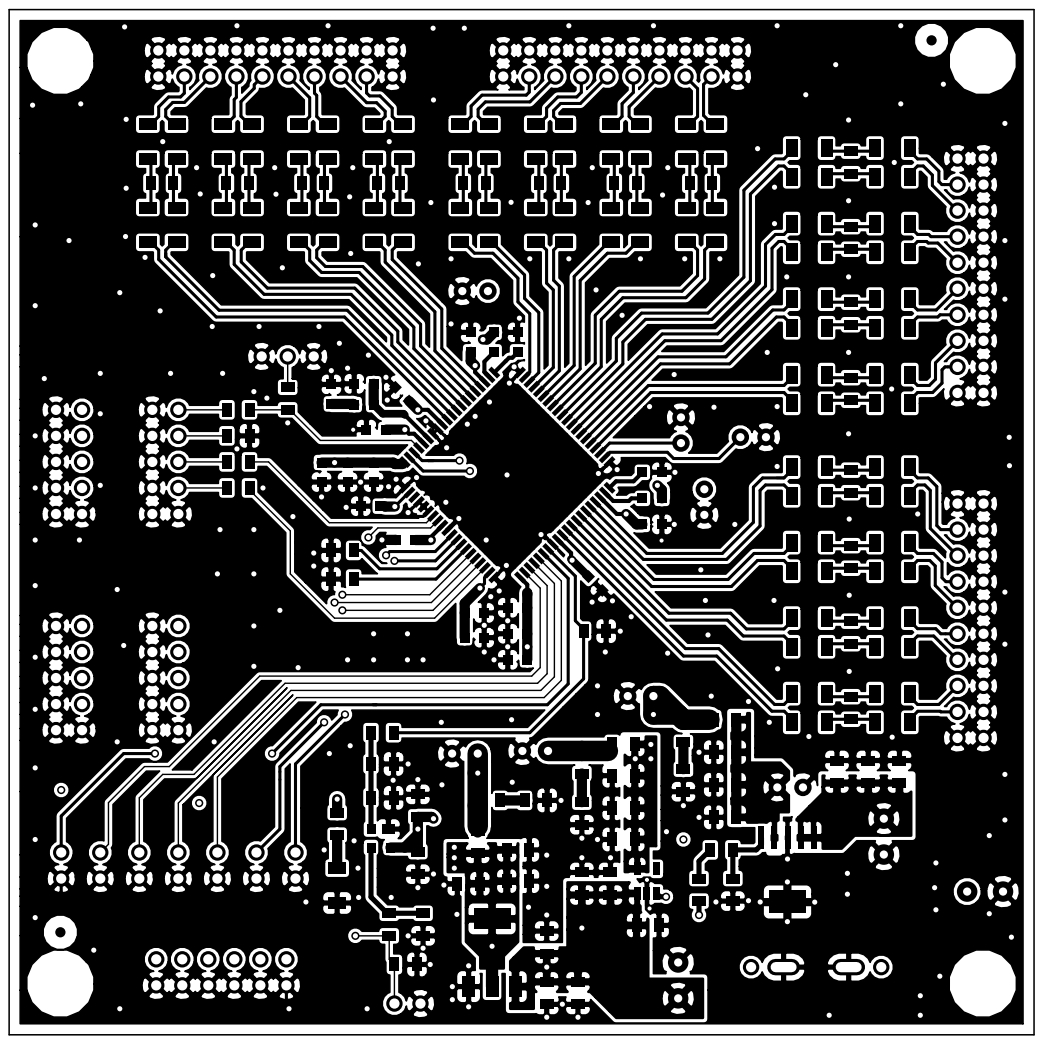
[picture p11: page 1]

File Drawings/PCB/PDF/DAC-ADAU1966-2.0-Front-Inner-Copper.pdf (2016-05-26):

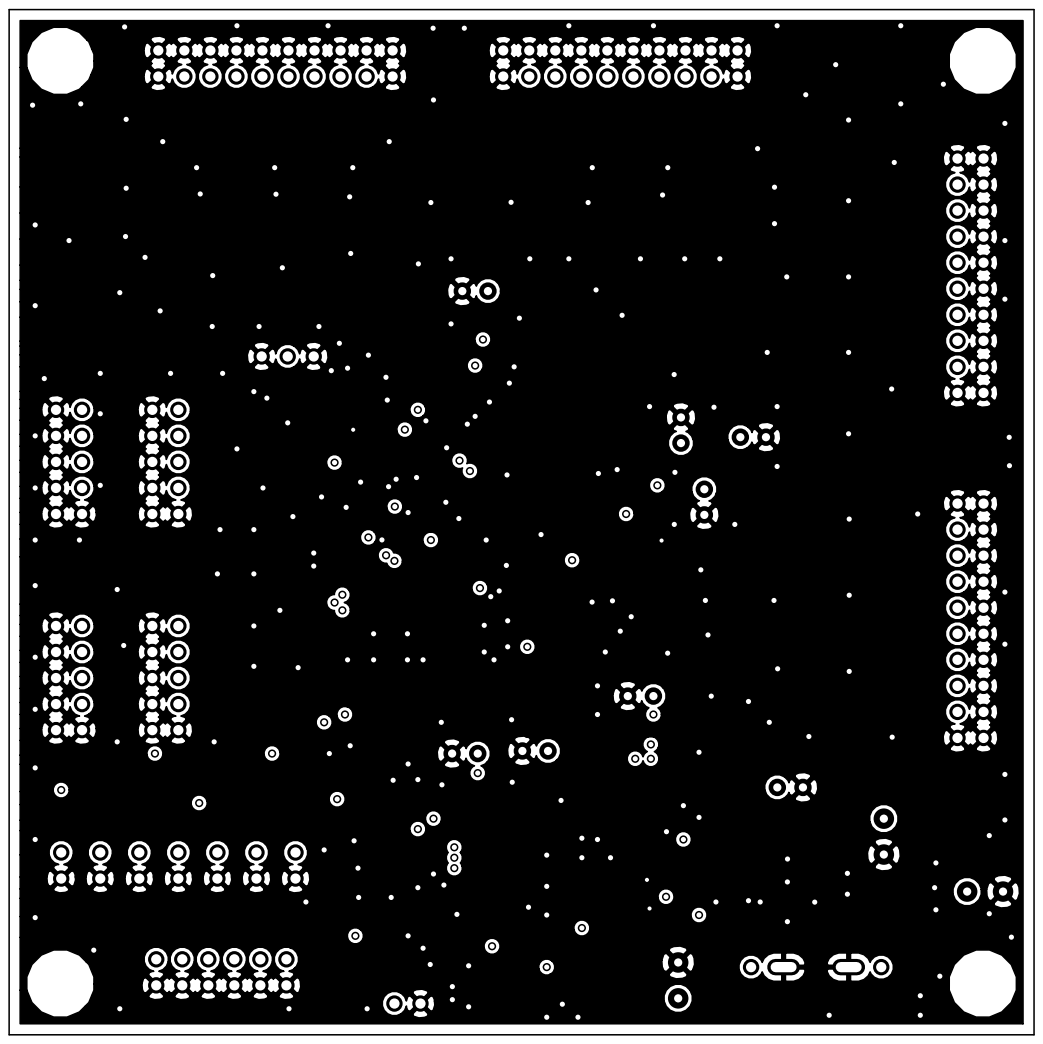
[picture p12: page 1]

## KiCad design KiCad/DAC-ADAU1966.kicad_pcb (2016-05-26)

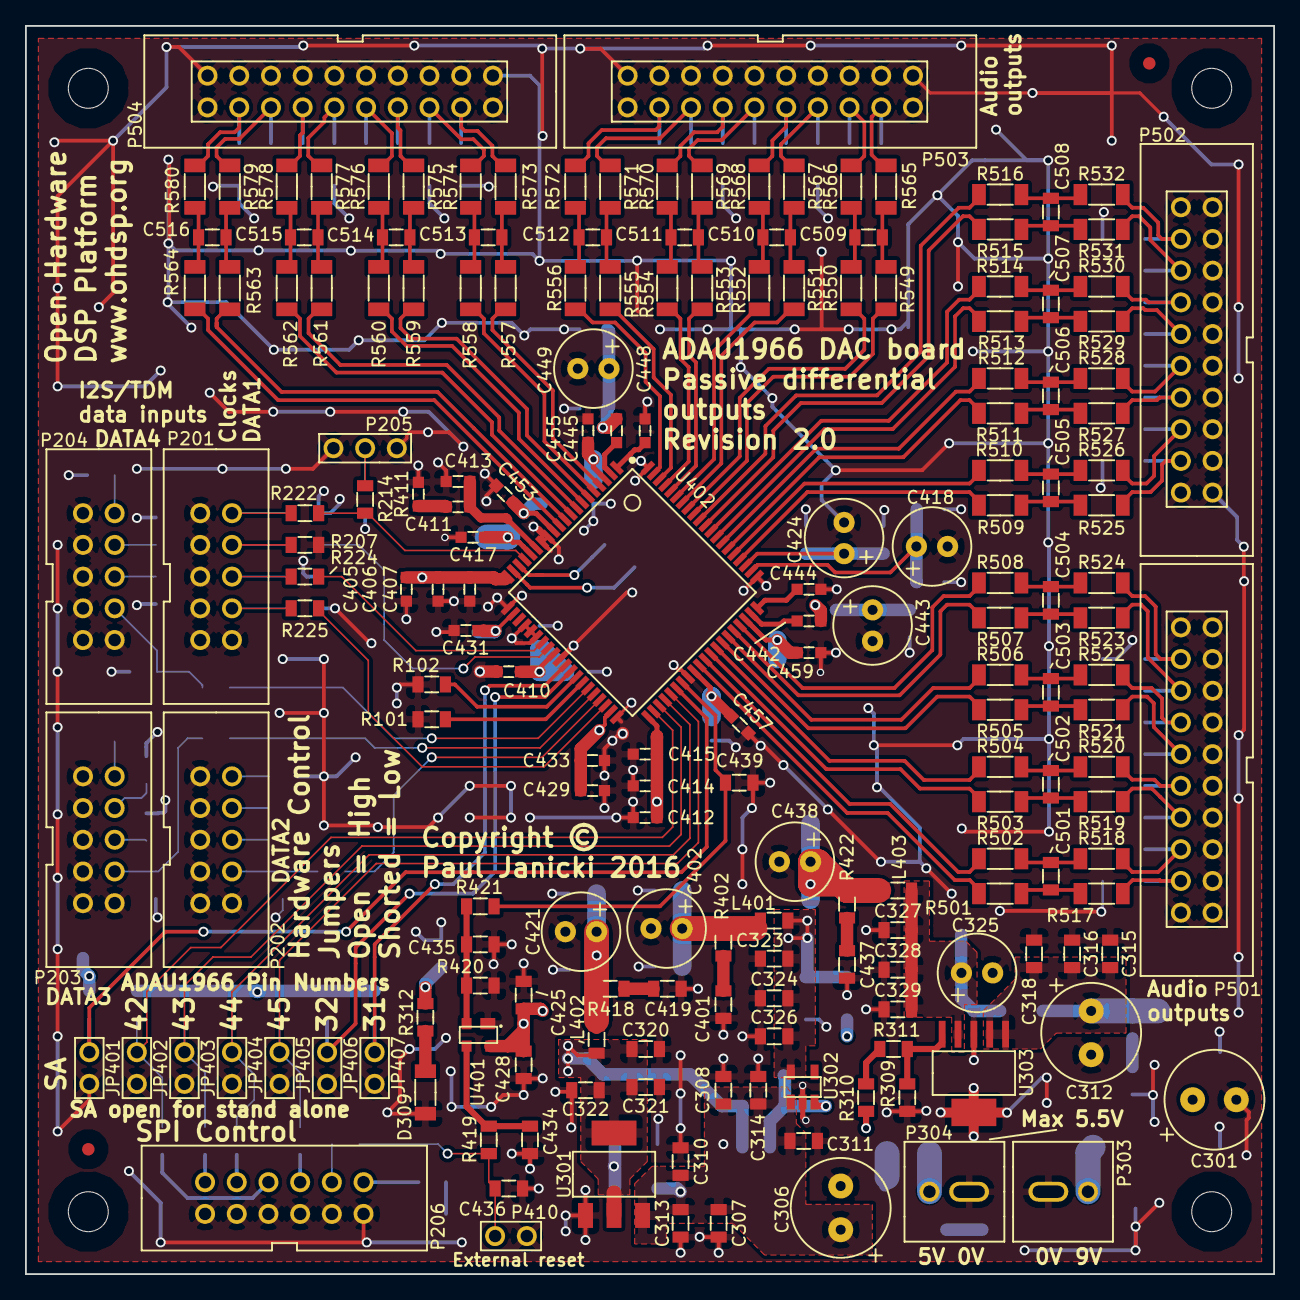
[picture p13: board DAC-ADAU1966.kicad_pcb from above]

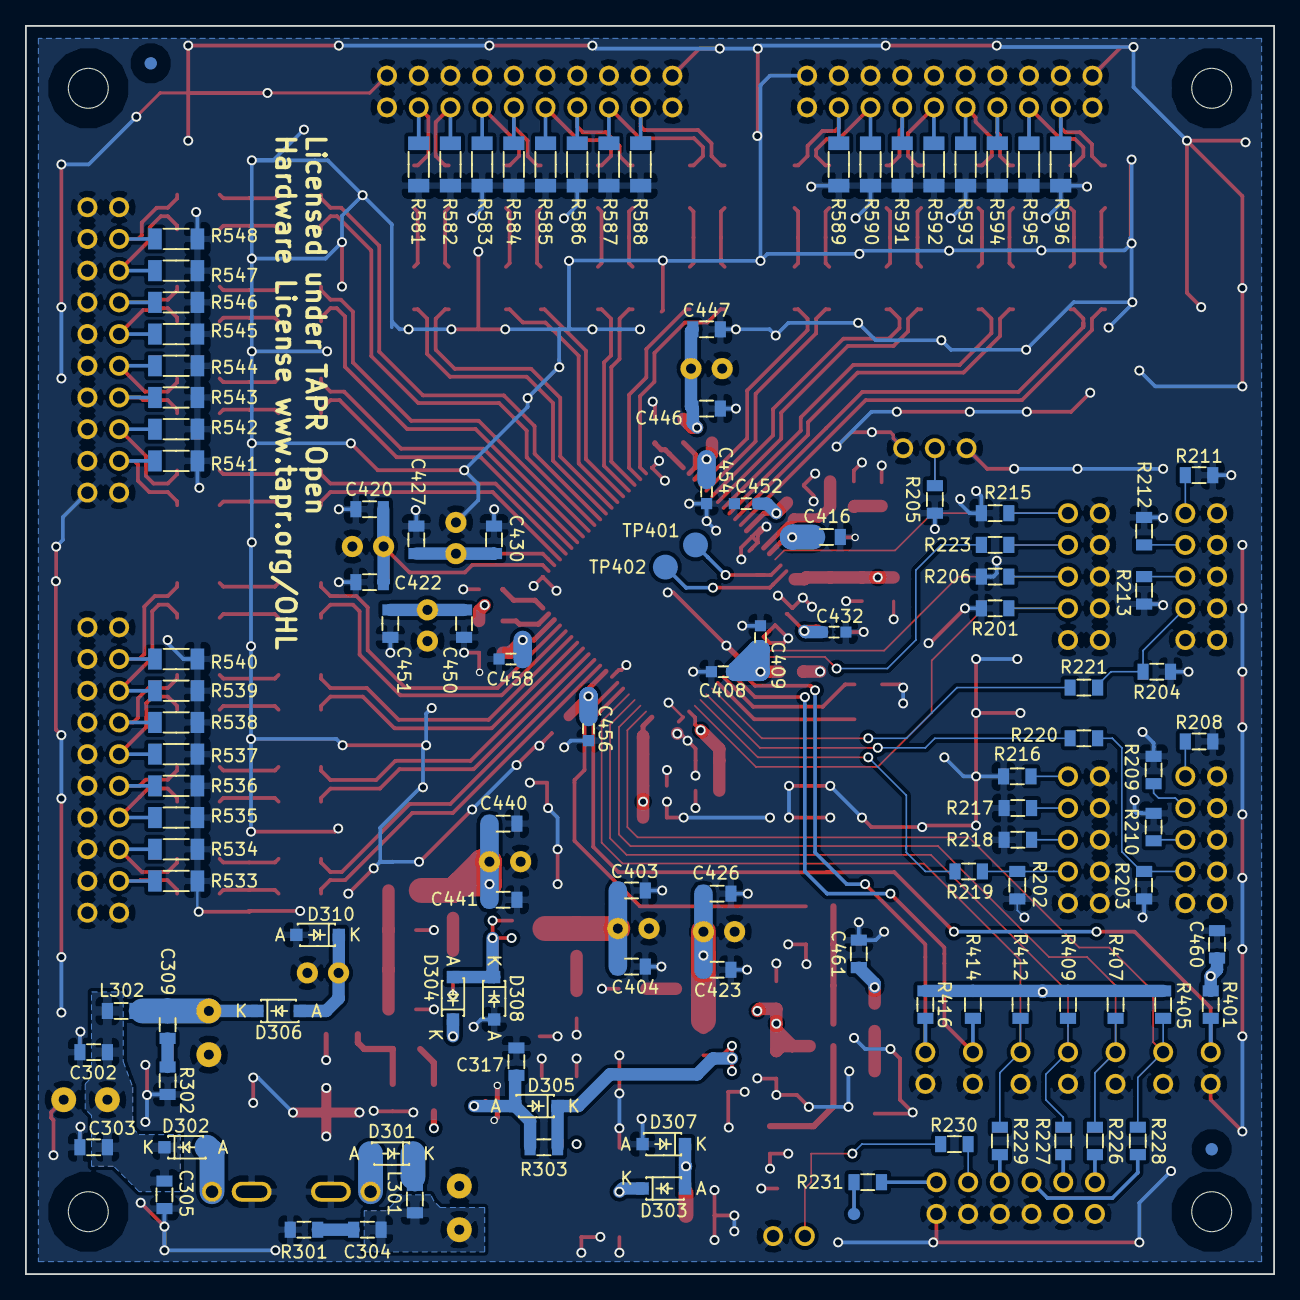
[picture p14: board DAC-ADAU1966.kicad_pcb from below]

Board: 4 copper layers, 100.0 x 100.0 mm, 306 parts (114 on the bottom side), 172 nets.

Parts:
C301, C306, C312: 220u; CAP-TH-D8mmP3.5mm
C302, C307, C308, C315, C317, C320, C323, C327, C403, C416, C420, C423, C427, C440: 22u; SMD-0805
C303, C310, C311, C316, C321, C324, C328, C404, C422, C426, C428, C430, C434, C436, C439, C441, C446, C450, C460: 100n; SMD-0805
C304, C309, C401, C419, C437: 100p; SMD-0805
C305, C313, C314, C318, C322, C326, C329, C447, C451: 10n; SMD-0805
C325, C402, C418, C421, C424, C438: 220u; CAP-TH-D6.3mmP2.5mm
C405, C408, C412, C429, C432, C452, C454, C456, C458: 1u; SMD-0603
C406, C409, C414, C417, C431, C433, C453, C455, C457, C459: 100n; SMD-0603
C407, C410, C415: 10n; SMD-0603
C411: 5n6; SMD-0603
C413: 390p; SMD-0603
C425, C461: 10u; SMD-0805
C435: N/F; SMD-0805
C442, C444, C445, C448: 470n; SMD-0603
C443, C449: 47u; CAP-TH-D6.3mmP2.5mm
C501, C502, C503, C504, C505, C506, C507, C508, C509, C510, C511, C512, C513, C514, C515, C516: 2n7; SMD-0805
D301, D302, D303, D304, D306, D307, D308, D310: SS14L; DIODE-SOD-123
D305: B130LAW-7-F; DIODE-SOD-123
D309: Green LED 1206; SMD-1206
FID1, FID2, FID3, FID4: MNT_HOLE; FID-1MM-3MM
JP401, JP402, JP403, JP404, JP405, JP406, JP407: CONN_2x1; CONN_SIL_2_1MM
L301, L302, L401, L402, L403: 600R@100MHz; SMD-0805
MNT301, MNT302, MNT303, MNT304: MNT_HOLE; MNT_HOLE_3.2mm
P201, P202, P203, P204: CONN_02X05; CONN_DIL_2X5_BOX_1MM
P205: CONN_3x1; CONN_SIL_3_1MM
P206: CONN_02X06; CONN_DIL_2X6_BOX_1MM
P303, P304: CONN_2x1; CONN-2WAY-2.54mm-3.81mm-SPACING
P410: CONN_2x1; CONN_SIL_2_1MM
P501, P502, P503, P504: CONN_02X10; CONN_DIL_2X10_BOX_1MM
R101, R102, R419: 1k; SMD-0805
R201, R202, R203, R204, R205, R206, R207, R214, R215: N/F; SMD-0805
R208, R209, R210, R211, R212, R213, R216, R217, R218, R401, R405, R407, R409, R412, R414, R416: 10k; SMD-0805
R219, R220, R221, R222, R223, R224, R225, R227, R228, R229, R230, R231, R310: 0; SMD-0805
R226: 75; SMD-0805
R301, R302, R402, R418, R422: 47; SMD-0805
R303: 47k; SMD-0805
R309: 2k2; SMD-0805
R311: 6k8; SMD-0805
R312: 470; SMD-0805
R411: 562; SMD-0603
R420: 100k; SMD-0805
R421: 100; SMD-0805
R501, R502, R503, R504, R505, R506, R507, R508, R509, R510, R511, R512, R513, R514, R515, R516, R549, R550, R551, R552, R553, R554, R555, R556, R557, R558, R559, R560, R561, R562, R563, R564: 240; SMD-1206
R517, R518, R519, R520, R521, R522, R523, R524, R525, R526, R527, R528, R529, R530, R531, R532, R565, R566, R567, R568, R569, R570, R571, R572, R573, R574, R575, R576, R577, R578, R579, R580: 100; SMD-1206
R533, R534, R535, R536, R537, R538, R539, R540, R541, R542, R543, R544, R545, R546, R547, R548, R581, R582, R583, R584, R585, R586, R587, R588, R589, R590, R591, R592, R593, R594, R595, R596: 100k; SMD-1206
TP101: Test point; TP-1mm
TP401, TP402: Test point; TP-2mm
U301: TLV1117LV33DCY; IC-SOT-223
U302: TLV70025DDC; IC-SOT23-5
U303: TPS7A4501; IC-SOT223-6
U401: ADM811ZART; IC-SOT143
U402: IC-DAC-ADAU1966; IC-LQFP80-P065

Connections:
/ADAU1966/AVDD: C438.1, C440.1, C441.1, C442.1, C443.1, C445.1, C446.1, C447.1, C449.1, C450.1, C451.1, C452.1, C453.1, C454.1, C455.1, C456.1, C457.1, C458.1, C459.1, L403.2, R422.1, U402.3, U402.12, U402.49, U402.58
/ADAU1966/DACOUT_LRCLK: R223.2, U402.28
/ADAU1966/DACOUT_SDATA1: R225.2, U402.38
/ADAU1966/DACOUT_SDATA2: R219.2, U402.37
/ADAU1966/DACOUT_SDATA3: R220.2, U402.36
/ADAU1966/DACOUT_SDATA4: R221.2, U402.35
/ADAU1966/DACOUT_SDATA5: R101.1, U402.34
/ADAU1966/DACOUT_SDATA6: R102.1, U402.33
/ADAU1966/DAC_CLK: JP404.1, R227.1, R409.1, U402.44
/ADAU1966/DAC_CS: JP405.1, R229.1, R412.1, U402.45
/ADAU1966/DAC_MISO: JP403.1, R226.1, R407.1, U402.43
/ADAU1966/DAC_MOSI: JP402.1, R228.1, R405.1, U402.42
/ADAU1966/DAC_RESET: C439.1, R421.1, U402.47
/ADAU1966/DSDATA7: JP406.1, R414.1, U402.32
/ADAU1966/DSDATA8: JP407.1, R416.1, U402.31
/ADAU1966/DVDD: C402.1, C403.1, C404.1, C405.1, C406.1, C407.1, C408.1, C409.1, C410.1, C412.1, C414.1, C415.1, C416.1, C417.1, L401.2, R402.1, U402.16, U402.20, U402.29, U402.41
/ADAU1966/IOVDD: C421.1, C423.1, C426.1, C429.1, C431.1, C432.1, C433.1, L402.2, R418.1, U402.22, U402.39
/ADAU1966/LF: C411.1, C413.1, U402.15
/ADAU1966/MAN_RST_IN: C436.1, P410.1, R230.1, R419.2
/ADAU1966/MCLK: R214.2, R222.2, U402.17
/ADAU1966/OUT_1P: R501.1, U402.50
/ADAU1966/OUT_2P: R503.1, U402.52
/ADAU1966/OUT_3P: R505.1, U402.54
/ADAU1966/OUT_4P: R507.1, U402.56
/ADAU1966/OUT_5P: R509.1, U402.64
/ADAU1966/OUT_6P: R511.1, U402.66
/ADAU1966/OUT_7P: R513.1, U402.68
/ADAU1966/OUT_8P: R515.1, U402.70
/ADAU1966/OUT_9P: R549.1, U402.72
/ADAU1966/OUT_10P: R551.1, U402.74
/ADAU1966/OUT_11P: R553.1, U402.76
/ADAU1966/OUT_12P: R555.1, U402.78
/ADAU1966/OUT_13P: R557.1, U402.4
/ADAU1966/OUT_14P: R559.1, U402.6
/ADAU1966/OUT_15P: R561.1, U402.8
/ADAU1966/OUT_16P: R563.1, U402.10
/ADAU1966/SA: JP401.1, R401.1, U402.46
/AnaloguePassiveFilters/N1: R502.1, U402.51
/AnaloguePassiveFilters/N2: R504.1, U402.53
/AnaloguePassiveFilters/N3: R506.1, U402.55
/AnaloguePassiveFilters/N4: R508.1, U402.57
/AnaloguePassiveFilters/N5: R510.1, U402.65
/AnaloguePassiveFilters/N6: R512.1, U402.67
/AnaloguePassiveFilters/N7: R514.1, U402.69
/AnaloguePassiveFilters/N8: R516.1, U402.71
/AnaloguePassiveFilters/N9: R550.1, U402.73
/AnaloguePassiveFilters/N10: R552.1, U402.75
/AnaloguePassiveFilters/N11: R554.1, U402.77
/AnaloguePassiveFilters/N12: R556.1, U402.79
/AnaloguePassiveFilters/N13: R558.1, U402.5
/AnaloguePassiveFilters/N14: R560.1, U402.7
/AnaloguePassiveFilters/N15: R562.1, U402.9
/AnaloguePassiveFilters/N16: R564.1, U402.11
/Connectors/BCLK: R224.2, U402.27
/Connectors/GPIO: R231.1, TP101.1
GNDA: C301.2, C302.2, C303.2, C305.2, C306.2, C307.2, C308.2, C310.2, C311.2, C312.2, C313.2, C314.2, C315.2, C316.2, C317.2, C318.2, C320.2, C321.2, C322.2, C323.2, C324.2, C325.2, C326.2, C327.2, C328.2, C329.2, C401.2, C402.2, C403.2, C404.2, C405.2, C406.2, C407.2, C408.2, C409.2, C410.2, C412.2, C413.2, C414.2, C415.2, C416.2, C417.2, C418.2, C419.2, C420.2, C421.2, C422.2, C423.2, C424.2, C425.2, C426.2, C427.2, C428.2, C429.2, C430.2, C431.2, C432.2, C433.2, C434.2, C435.2, C436.2, C437.2, C438.2, C439.2, C440.2, C441.2, C443.2, C444.2, C446.2, C447.2, C448.2, C449.2, C450.2, C451.2, C452.2, C453.2, C454.2, C455.2, C456.2, C457.2, C458.2, C459.2, C460.2, C461.2, D307.1, D308.1, D309.2, D310.1, JP401.2, JP402.2, JP403.2, JP404.2, JP405.2, JP406.2, JP407.2, P201.1, P201.3, P201.5, P201.7, P201.9, P201.10, P202.1, P202.3, P202.5, P202.7, P202.9, P202.10, P203.1, P203.3, P203.5, P203.7, P203.9, P203.10, P204.1, P204.3, P204.5, P204.7, P204.9, P204.10, P205.1, P205.3, P206.1, P206.3, P206.5, P206.7, P206.9, P206.11, P303.2, P304.2, P410.2, P501.1, P501.2, P501.3, P501.5, P501.7, P501.9, P501.11, P501.13, P501.15, P501.17, P501.19, P501.20, P502.1, P502.2, P502.3, P502.5, P502.7, P502.9, P502.11, P502.13, P502.15, P502.17, P502.19, P502.20, P503.1, P503.2, P503.3, P503.5, P503.7, P503.9, P503.11, P503.13, P503.15, P503.17, P503.19, P503.20, P504.1, P504.2, P504.3, P504.5, P504.7, P504.9, P504.11, P504.13, P504.15, P504.17, P504.19, P504.20, R101.2, R102.2, R201.1, R202.1, R203.1, R204.1, R205.1, R206.1, R207.1, R208.2, R209.2, R210.2, R211.2, R212.2, R213.2, R215.1, R216.2, R217.2, R218.2, R301.2, R302.2, R309.2, R411.2, R420.1, R533.2, R534.2, R535.2, R536.2, R537.2, R538.2, R539.2, R540.2, R541.2, R542.2, R543.2, R544.2, R545.2, R546.2, R547.2, R548.2, R581.2, R582.2, R583.2, R584.2, R585.2, R586.2, R587.2, R588.2, R589.2, R590.2, R591.2, R592.2, R593.2, R594.2, R595.2, R596.2, U301.1, U302.2, U303.3, U401.1, U402.13, U402.14, U402.21, U402.24, U402.25, U402.26, U402.30, U402.40, U402.48, U402.61, U402.80
unnamed: C301.1, C302.1, C303.1, C305.1, D302.2, L302.1
unnamed: C304.1, C306.1, C307.1, C308.1, C310.1, C311.1, C313.1, C314.1, D303.2, D304.2, L301.2, U301.3, U302.1
unnamed: C304.2, R301.1
unnamed: C309.1, C312.1, C315.1, C316.1, C318.1, D306.2, L302.2, U303.1, U303.2
unnamed: C309.2, R302.1
unnamed: C317.1, D305.1, R303.2, U302.3
unnamed: C401.1, R402.2
unnamed: C411.2, R411.1
unnamed: C418.1, C420.1, C422.1, U402.62
unnamed: C419.1, R418.2
unnamed: C424.1, C427.1, C430.1, U402.63
unnamed: C434.1, R419.1, U401.3
unnamed: C435.1, R420.2, R421.2, U401.2
unnamed: C437.1, R422.2
unnamed: C442.2, U402.59
unnamed: C444.1, U402.60
unnamed: C445.2, U402.2
unnamed: C448.1, U402.1
unnamed: C501.1, R502.2, R518.1
unnamed: C501.2, R501.2, R517.1
unnamed: C502.1, R504.2, R520.1
unnamed: C502.2, R503.2, R519.1
unnamed: C503.1, R506.2, R522.1
unnamed: C503.2, R505.2, R521.1
unnamed: C504.1, R508.2, R524.1
unnamed: C504.2, R507.2, R523.1
unnamed: C505.1, R510.2, R526.1
unnamed: C505.2, R509.2, R525.1
unnamed: C506.1, R512.2, R528.1
unnamed: C506.2, R511.2, R527.1
unnamed: C507.1, R514.2, R530.1
unnamed: C507.2, R513.2, R529.1
unnamed: C508.1, R516.2, R532.1
unnamed: C508.2, R515.2, R531.1
unnamed: C509.1, R550.2, R566.1
unnamed: C509.2, R549.2, R565.1
unnamed: C510.1, R552.2, R568.1
unnamed: C510.2, R551.2, R567.1
unnamed: C511.1, R554.2, R570.1
unnamed: C511.2, R553.2, R569.1
unnamed: C512.1, R556.2, R572.1
unnamed: C512.2, R555.2, R571.1
unnamed: C513.1, R558.2, R574.1
unnamed: C513.2, R557.2, R573.1
unnamed: C514.1, R560.2, R576.1
unnamed: C514.2, R559.2, R575.1
unnamed: C515.1, R562.2, R578.1
unnamed: C515.2, R561.2, R577.1
unnamed: C516.1, R564.2, R580.1
unnamed: C516.2, R563.2, R579.1
unnamed: D301.1, P304.1
unnamed: D301.2, L301.1
unnamed: D302.1, P303.1
unnamed: D309.1, R312.2
unnamed: P201.2, R215.2, R222.1
unnamed: P201.4, R207.2, R223.1
unnamed: P201.6, R206.2, R224.1
unnamed: P201.8, R201.2, R225.1
unnamed: P202.2, R216.1
unnamed: P202.4, R217.1
unnamed: P202.6, R218.1
unnamed: P202.8, R202.2, R219.1
unnamed: P203.2, R208.1
unnamed: P203.4, R209.1
unnamed: P203.6, R210.1
unnamed: P203.8, R203.2, R220.1
unnamed: P204.2, R211.1
unnamed: P204.4, R212.1
unnamed: P204.6, R213.1
unnamed: P204.8, R204.2, R221.1
unnamed: P205.2, R205.2, R214.1
unnamed: P206.2, R226.2
unnamed: P206.4, R227.2
unnamed: P206.6, R228.2
unnamed: P206.8, R229.2
unnamed: P206.10, R230.2
unnamed: P206.12, R231.2
unnamed: P501.4, R517.2, R533.1
unnamed: P501.6, R518.2, R534.1
unnamed: P501.8, R519.2, R535.1
unnamed: P501.10, R520.2, R536.1
unnamed: P501.12, R521.2, R537.1
unnamed: P501.14, R522.2, R538.1
unnamed: P501.16, R523.2, R539.1
unnamed: P501.18, R524.2, R540.1
unnamed: P502.4, R525.2, R541.1
unnamed: P502.6, R526.2, R542.1
unnamed: P502.8, R527.2, R543.1
unnamed: P502.10, R528.2, R544.1
unnamed: P502.12, R529.2, R545.1
unnamed: P502.14, R530.2, R546.1
unnamed: P502.16, R531.2, R547.1
unnamed: P502.18, R532.2, R548.1
unnamed: P503.4, R565.2, R581.1
unnamed: P503.6, R566.2, R582.1
unnamed: P503.8, R567.2, R583.1
unnamed: P503.10, R568.2, R584.1
unnamed: P503.12, R569.2, R585.1
unnamed: P503.14, R570.2, R586.1
unnamed: P503.16, R571.2, R587.1
unnamed: P503.18, R572.2, R588.1
unnamed: P504.4, R573.2, R589.1
unnamed: P504.6, R574.2, R590.1
unnamed: P504.8, R575.2, R591.1
unnamed: P504.10, R576.2, R592.1
unnamed: P504.12, R577.2, R593.1
unnamed: P504.14, R578.2, R594.1
unnamed: P504.16, R579.2, R595.1
unnamed: P504.18, R580.2, R596.1
unnamed: R309.1, R311.2, U303.5
unnamed: R310.1, R311.1
unnamed: TP401.1, U402.18
unnamed: TP402.1, U402.19
VAA: C325.1, C327.1, C328.1, C329.1, D306.1, D310.2, L403.1, R310.2, U303.4
VDD: C323.1, C324.1, C326.1, C425.1, C428.1, D304.1, D308.2, L401.1, U302.5, U401.4
VPP: C320.1, C321.1, C322.1, C460.1, C461.1, D303.1, D305.2, D307.2, L402.1, R303.1, R312.1, R401.2, R405.2, R407.2, R409.2, R412.2, R414.2, R416.2, U301.2

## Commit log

2016-01-24 Release 1.0
    Release 1.0
    [ADAU1966.sch, AnaloguePassiveFilters.sch, Connectors.sch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]
2016-05-26 Revision 2.0
    [ADAU1966.sch, AnaloguePassiveFilters.sch, Connectors.sch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]
2016-07-01 Revision 2.0
    Update BOM sheet name
    [DAC-ADAU1966-PassiveFilters-2.0-Bill-of-Materials.ods]

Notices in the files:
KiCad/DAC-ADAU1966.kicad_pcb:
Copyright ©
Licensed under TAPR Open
